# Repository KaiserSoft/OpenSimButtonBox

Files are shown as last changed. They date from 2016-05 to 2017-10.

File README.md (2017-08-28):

Modular Open Sim Racing Button Box
==================================

The Modular Open Button Box (MOBB) project is a complete open source solution to build your own button box. It provides complete plans on how to build your own 
Teensy 3.2 shield, button box ideas, box designs for 3D printers, drill tempaltes for your face plates or just ideas for your own design.    
The design is modular so you may pick and choose from various parts to design YOUR button box the way YOU imagine it.    

example image of the Open Button Box (MOBB) PCB rev5    

Design idea with UV-LEDs to provide illumunation when it is dark
design idea with UV-LEDs

Side by side box design    
side by side sim button box

Two of the boxes used for current development    
two development button boxes

Example of pit limiter switch on older development board   
pit limiter switch example

The PCB
===========
The PCB is a shield for the Teensy 3.2 micro controller board. You may use the provided schematic to build your own on a perfboard, use the provided gerber files to have one manfucatured or contact me to send you one.    
Assembly requires minor soldering skills but assembly is quite easy if you follow the instruction videos.       

The current version supports
* through hole component design for easy soldering
* 32 buttons
* 1 latching toggle switch with LED inside - used to enable/disable the pit limiter
* 3 rotary encoders
* 3 Auxillary ports providing 0-5Volt @ 100mA each
* one handed operation to adjust AUX ports (always have one hand on the steering wheel)
* fully open source in design and code
* code written using the Arduino IDE for easy customizations
* (Optional) 12Volt Fan Board with optical isolation between 12Volt supply and host PC. Connects to one AUX port and controls up to two fans.
image of fan controller board

INSTRUCTIONS & Sources List
===========================
Any documentation in the "Documentation" directory is not up to date anymore!    
I will produce a series of videos explaining how to build the PCB and how to configure the software.     
The build video is available here https://www.youtube.com/watch?v=iexbjr4jJTc      

This is an open source project - contributions are welcome!

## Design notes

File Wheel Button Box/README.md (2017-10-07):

OSW Button Box - DIY Direct Drive Wheel Button Box
===

Image of fully assembled wheel button box

Required Parts
===
* Arduino Pro Micro 16MHz - Will not work with most other Arduinos since they can not act as a HID. Teensy should work as well but it is more expensive.
* 10x push buttons with a thread diameter of around 12mm. The kind with a metal body works as well but they are heavier.    
  Supported Push Buttons
* 1x Arduino Joystick Module - pay close attention to the circuit board since there are different types and the button box only works when the dimensions are correct.  
  Supported Joystick Module
* Coiled Micro USB Cable - this connects the button box to your PC. It needs to be coiled so it can flex all the way to the end stops.

Build Instructions
===
* Print the button box and do basic cleanup. Rough up the sides where the box is split and use glue to join the two halves back together. You don't need much glue since this only makes it easier to install the buttons and cables. The button box will be held in place by the screws connecting the wheel to the mounting hub on the OSW motor.
* Install the buttons and solder the wires in place. Cut the wires long enough so that they can exit the arduino box at the bottom.
* Desolder the connection pin header on your joystick module.
* Solder wires to the joystick module and run them to the arduino box as well
* Ensure that every button is working by using the continuity test setting on your multi meter
* Ensure the joystick is working by testing the resistance
* Add wires for the magnetic paddle shifters as well. I recommend that you don't connect the sifters yet. Simply run wires and solder them to the paddle shifter wires once you are ready to assemble it all.
* Connect all wires as described in "CONFIG.h". Buttons use the "Button_X_Pin" and the joystick the "Joystick_X_Pin" setting.
* Remove some of the plastic on the outside of the micro USB connector. This makes the connector shorter and makes in easier to push it through the hole inside the button box.
* Connect the coiled USB cable to the arduino and upload the scetch to the board
* Test every button and joystick
* Test the buttons again
* Push the arduino into the arduino box at the bottom. Pull extra wires into the button box body and hide them in the wire channel.
* Test the buttons again
* Fill the arduino box with hot glue or silicone sealant. This ensures that the micro USB connector will not disconnect and that the arduino will not move
* Run the rest of the USB cable through wire channel at the bottom of the unit
* Assemble everything and connect the padde shifters
* Mount everything to the OSW and attach the wheel
* All done. You can use the arduino software to change which button sends which command (CONFIG.h file)
* Have fun!
image showing sections described above

Recommended Print / Slicer Settings
===
* Material: PLA
* Layer height: 0.25mm
* Infill: 25% to 30%
* Top/Bottom: 3 solid layers

File and Directory List
===
* **arduino_pro-micro_button_box**    
  This directory contains the Arduino Pro Micro Source Code

* **Face Plate for 320mm Steering Wheel**   
  Contains the STL and 3D source models for the button face plate
  
* **Wheel Box Face Plate for Arduino ProMicro - ONE PIECE**    
  This STL file contains the face plate in one piece. You need about a 200mmx150mm build surface.
  
*  **Wheel Box Face Plate for Arduino ProMicro - TWO PIECES - ONE / TWO**    
  This STL file as the face plate split into two pieces. This will work with a standard 150mmx150mm build surface
  
* **Sparko - Momo - Spacer and Backplate - ProMicro**    
  This is the back plate required to keep the center joystick in place
  
* **Shifter Mount with Joystick Slot**    
  This file contains the paddle shifter mount plate

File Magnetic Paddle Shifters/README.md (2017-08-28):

3D Printed Magnetic Paddle Shifter
---

These 3D printed magnetic paddle shifters are designed to be compatible with most button boxes used in the sim racing community.
The shifter is designed to be compatible with the Omron D2F-01 micro switch. You may use the original Omron part or get cheap knock offs from ebay. 
   
The shifters only require a few parts and are easy to print. Please have a look at the build instruction video for more detail on how to assemble one.

https://www.youtube.com/watch?v=kEENwVqYf5s   

File Overview
---
* The folder "Box Style" contains the current design. It is simpler to build and uses stronger parts when compared to the "Open Design".
* The folder "Paddles" contains different paddle designs. You only need one per shifter.
* The folder "Open Design" contains the older "open style" design. It is more complicated to build and requires exact distance between the lever and the switch. You probably don't want to use this.

Recommended printer/slicer settings
---
* The shifter body should be printed with at least 20% honeycomb infill
* The lever should be printed solid
* The paddles work great with 30% honeycomb infill
* The part is build with a 0.25mm layer height in mind
* Material used for my prints is PLA

Bill of Materials
---
The following parts are required to assemble one shifter unit. Each shifter requires on micro switch. The type 
depends on which Body you are printing.

* 2x 623ZZ ball bearing
* 1x M3x45mm flat head machine screw
* 1x M3 nut / locking nut for machine screw
* 2x 12x3mm neodymium magnet (round disk shape). 
You may order additional magnets to adjust the force required. I recommend at least one more 12x2mm
* 2x M3x12mm counter sunk screw for mounting the paddles to the shift lever
* 2x M3 nut for the M3x12mm counter sunk screw
* 2x M3 countersunk screw for mounting the unit to your button box or wheel
* 1x Omron D2F-01 or D2F-01-D3 micro switch or cheap clones D2FC-F-7N on ebay

Media
---
List of videos related to these magnetic paddle shifters
* Assembly video - https://www.youtube.com/watch?v=kEENwVqYf5s
* Magnetic Paddle Shifter durability testing (open design) - https://www.youtube.com/watch?v=JnYoWvMd-ec
* Testing in game, mounted to G27 wheel base (open design)  - https://www.youtube.com/watch?v=P4YznCb-aOs
* Testing with OSW direct drive wheel (open design)  - https://www.youtube.com/watch?v=NF07MALhuUw

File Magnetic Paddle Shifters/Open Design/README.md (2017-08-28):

3D Printed Magnetic Paddle Shifter - Open Design
---
Please note, this design has been replaced by the "Box Style" since the box style is easier to build and used stronger components. This design still works fine but I don't recommend you use it if you are building a new set of paddle shifters.
   
These 3D printed magnetic paddle shifters are designed to be compatible with most button boxes used in the sim racing community.
There are two versions of the shifter. One is for a micro switch with "pin plunger", like the Omron D2F-01. The other version is for a micro switch with "hinge lever", like the Omron D2F-01L.   
The "pin plunger" version requires a more accurate printer since it is using tighter tolerances. The "hinge lever" part is more flexible with dimensional accuracy but the "hinge lever" switch may not be as reliable.
   
The shifters only require a few parts and are easy to print. Please have a look at the build instruction video for more detail on how to assemble one.

https://www.youtube.com/watch?v=EhsOMB1wswM 

Recommended printer/slicer settings
---
* The shifter body should be printed with at least 15% infill
* The lever should be printed solid
* The paddles work great with 30% honeycomb infill
* The part is build with a 0.25mm layer height in mind
* Material used for my prints is PLA

File Overview
---
* The folder "Body for Pin Plunger Switch" contains the body part designed for the "pin plunger" type of button
* The folder "Body for Hinge Lever Switch" contains the body part designed for the "hinge lever" type of button
* The folder "Lever" contains the Lever used by both body styles

Bill of Materials
---
The following parts are required to assemble one shifter unit. Each shifter requires on micro switch. The type 
depends on which Body you are printing.

* 2x MR52ZZ ball bearing
* 1x M2x40mm flat head machine screw
* 1x M2 nut for machine screw
* 2x 12x3mm neodymium magnet (round disk shape)
* 2x M3x10mm counter sunk screw for mounting the paddles to the shift lever
* 2x M3 nut for the M3x10mm counter sunk screw
* 2x M3 countersunk screw for mounting the unit to your button box or wheel
* 1x Omron D2F-01 or D2F-01-D3 micro switch or cheap clones D2FC-F-7N on ebay (Body for Pin Plunger Switch)
* 1x Omron D2F-01L or D2F-01L-D3 micro switch (Body for Hinge Lever Switch)

Media
---
List of videos related to these magnetic paddle shifters
* Magnetic Paddle Shifter durability testing - https://www.youtube.com/watch?v=JnYoWvMd-ec
* First assembly video - https://www.youtube.com/watch?v=EhsOMB1wswM
* Second assembly video - https://www.youtube.com/watch?v=DKPDk3TvZT4
* Testing with OSW direct drive wheel - https://www.youtube.com/watch?v=NF07MALhuUw

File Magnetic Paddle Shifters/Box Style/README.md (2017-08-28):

Overview Box Style
---

Please see README.md in the "Magnetic Paddle Shifters" directory. This file only explains the different file types.

* SLDPRT - these are the main 3D model files. CAD software is Solidworks 2014
* STEP - these are exports of the SLDPRT file. You should be able to use these to import the 3D model into the CAD software of your choice.
* STL - these are the files you may use to print the object. These are oriented correctly so just add them to your slicer to create the gcode file for your printer.

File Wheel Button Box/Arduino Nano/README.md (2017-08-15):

Arduino Nano Button Box
---

Update 2017-08-15
WARNING: The code in this directory is not finished. The serial communication from the Arduino Nano to the VB.NET program is working but 
I ran into an issue when I tried to send the key presses to iRacing. It works in Windows Editor, other programs and even the iRacing chat box but 
it stops working once I enter the car. This may be an issue with which window has focus so the solution may be to detect the iracing window and 
explicitly send the output to it. I may investigate in the future or if someone else feels like testing it .... feel free.
I have decided to switch to an Arduino Pro Micro since that unit is about the same price as the Nano but offers USB HID support out of the box.
This will eliminate the requirement for the VB.NET program to send the keypresses since the Pro Micro will act as a true HID.
I was not aware of the Pro Micro before, that would have been the better solution to begin with.... I am also investigating using an STM32 since they are also very cheap and very capable. This will be a great replacement for the rather expensive Teensy 3.2

ANYWAY - DO NOT USE THE CODE IN THIS DIRECTORY AND EXPECT IT TO WORK IN GAME! - You have been warned!
/End of Update 2017-08-15

DO NOT USE THIS YET! This is mostly just code to test the concept!

This directory will contain the code for the arduino nano  to work as a simple stand alone button box
and a very simple Windows VB.NET programm to receive the button presses via the serial interface.
Since the Nano can not run as a HID the Windows programm will send the keystrokes to the computer.

Arduino Nano Pinout
---
This button box will support up to 13 push buttons with one analog joystick
The pinout is defined like this:

* D2-D8,D11,D12 are used for push buttons - 9 Buttons
* D13 feedback LED
* A0,A1,A2,A3 are used for push buttons - 4 Buttons
* A6 used for Joystick 1 x/y-axis
* A7 used for Joystick 1 x/y-axis
* D9-D10 reserved for other functions (PWM pins)
* A4,A5 reserved for possible i2c OLED display or LED RPM bar using i2C port extenders

Windows Receiver
---
Windows Receiver is a very simple VB.NET program which listens to specific commands.
It will work with any other micro controller as long as it follows the following rules.
Supported Commands:
	* 'wr' - Windows Receiver will send this on the serial port after the "Connect" button is pressed.
	* 'nr' - Windows Receiver expects to receive this after sending 'wr'. It will not accept button commands without receiving this string
	* 'ws' - Windows Receiver sends it before closing the serial port. The Arduino Nano must stop sending button commands once this has been received
	* 'ns' - Windows Receiver expects to receive this after 'ws' has been sent.
	* 'B[1-13]' - The Arduino Nano may send button presses by indicating which button was pressed. Example: 'B1', 'B2', 'B6' .....     
		The button number must match the setting in the Windows Receiver GUI
	* 'J[1-2]' - Just like button but for analog "jostick". Send 'J1' or 'J2' for one direcion where the number must match the GUI
	* 'K[1-2]' - Sends 'K' instead of 'J' when the same axis is moved in the opposite direction

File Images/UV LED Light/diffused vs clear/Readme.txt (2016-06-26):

LEDs have been diffused with fine sandpaper. 
Diffused LED focus the light much closer which should be much better to illuminate the button box labels.

The LEDs in the image where bought on Amazon.de
"10 Stück 10mm Ultra hell UV-LED " or "10 piece 10mm ulta bright UV-LED"

Specs:
Color: Ultraviolet
Size: 10mm
Lens type: clear
Wave length: 400-405nm
light intensity: 80-120mcd
DC current: 20mA
DC forward voltage: 3,2-3.4V

https://www.amazon.de/St%C3%BCck-10mm-Ultra-hell-UV-LED/dp/B008U1OEIK

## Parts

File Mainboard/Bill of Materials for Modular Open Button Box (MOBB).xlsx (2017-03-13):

Modular Open Button Box (MOBB) PCB rev 1.0 - Bill of Materials for non-SMD design
QTY | Name | PCB Reference | Comment / Values / Package
4 | 74HC4051 | U1, U2, U3, U4 | DIP-16
4 | NPN (CBE) Transistor | Q1, Q2, Q3, Q4 | 5V/100mA (CBE) TO-92
2 | PTC fuse | PTC1, PTC2 | Ihold:0.30/Itrip0.60A
1 | IC Socket for Teensy | U5 | DIP-28 with:15.24mm
3 | 10K (9+1 pin) resistor network | RR1, RR2, RR3 | star configuration, 2.54mm pitch
1 | 10K (5+1 pin) resistor network | RR4 | star configuration, 2.54mm pitch
1 | 100K 1/4Watt resistor | R10
1 | 10K 1/4Watt resistor | R1
1 | 10K (10pin) resistor network | RR5 | parallel configuration, 2.54mm pitch NOTE: may use 5x 10K 1/4Watt resistors instead
1 | 1K (10pin) resistor network | RR6 | parallel configuration, 2.54mm pitch NOTE: may use 5x 1K 1/4Watt resistors instead
1 | 1x2 pin header straight | P7 | 2.54mm pitch
1 | 1x2 pin header angled | P4 | 2.54mm pitch
1 | 1x6 pin header angled | P5 | 2.54mm pitch
2 | 2x3 pin header angled | P1, P3 | 2.54mm pitch
1 | 1x32 pin header angled | P6 | 2.54mm pitch
1 | 1x5 pin header angled | P14 | OPTIONAL: for "Extra Pins" - not used
1 | 5cm hookup wire | P2 | for +12V source
1 | 1x1 pin header connector |  | for hookup wire on P2, connector for Teensy side
1 | 10V 100uF electrolytic capacitor | C7 | radial, 2mm pitch

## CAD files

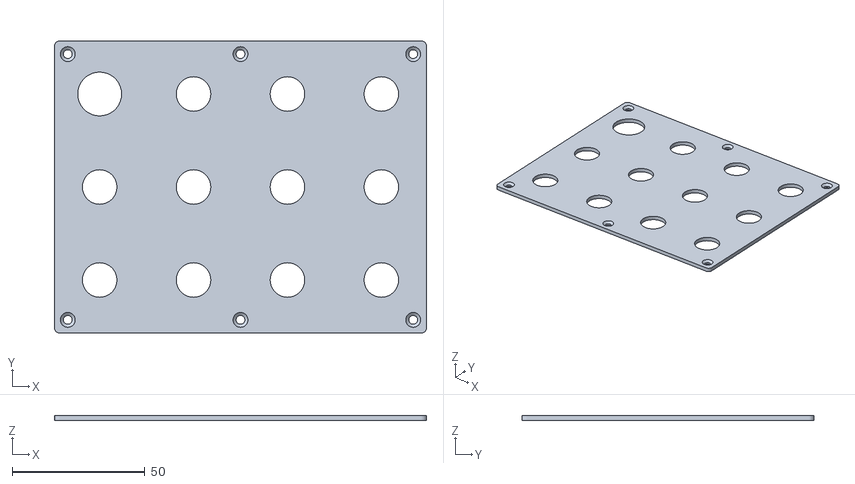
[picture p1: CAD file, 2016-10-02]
Cases and Enclosures/140mm wide/STL/Main Module - Face Plate - v5 - TOP ROW 1x16mm + 3x13mm - NO ENCODERS.STL
140.0 x 110.0 x 2.00

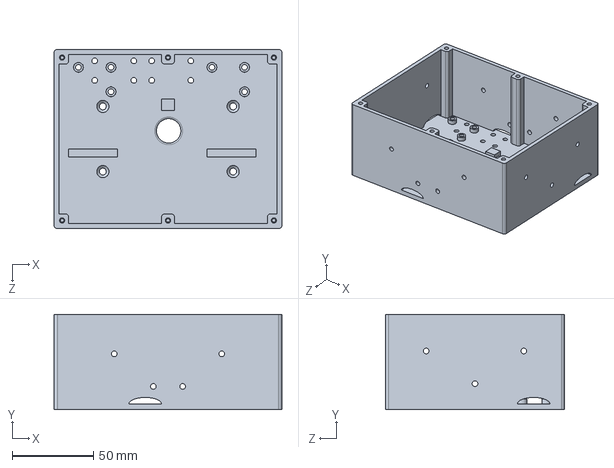
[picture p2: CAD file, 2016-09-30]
Main Module/Case/140mm wide/Main Module - Body - v5.SLDPRT
140.0 x 58.5 x 110.0 mm

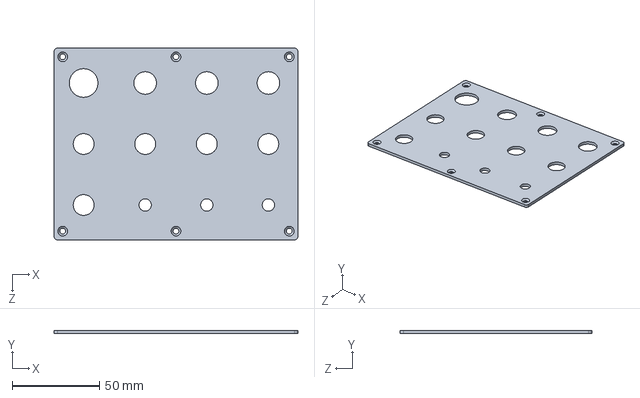
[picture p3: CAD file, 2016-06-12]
Main Module/Case/140mm wide/Main Module - Face Plate - v4.SLDPRT
140.0 x 2.00 x 110.0 mm

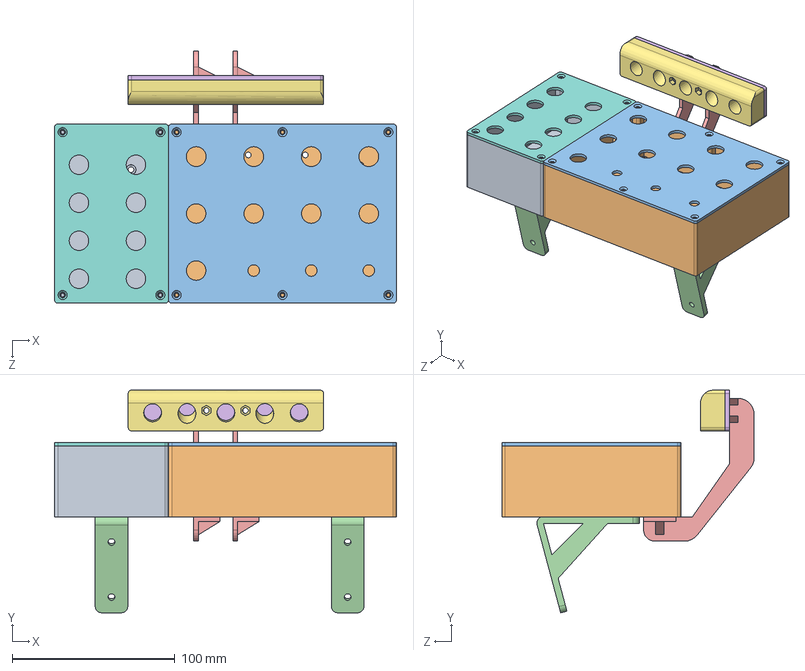
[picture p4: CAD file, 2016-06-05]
Cases and Enclosures/Side Box Left/Side Box Left assembled with Main Body - v2 Face Plate.SLDASM
210.0 x 136.8 x 154.9 mm
Side Box Left - Body - v2
Main Module - Body - v4
Main Module - Face Plate - v4
Mount Bracket 75 x 2
UV Lamp Mount - 10mm LED - MOUNT x 2
UV Lamp Mount - 10mm LED - COVER
UV Lamp Mount - 10mm LED - BASE
Side Box Left - Face Plate v2

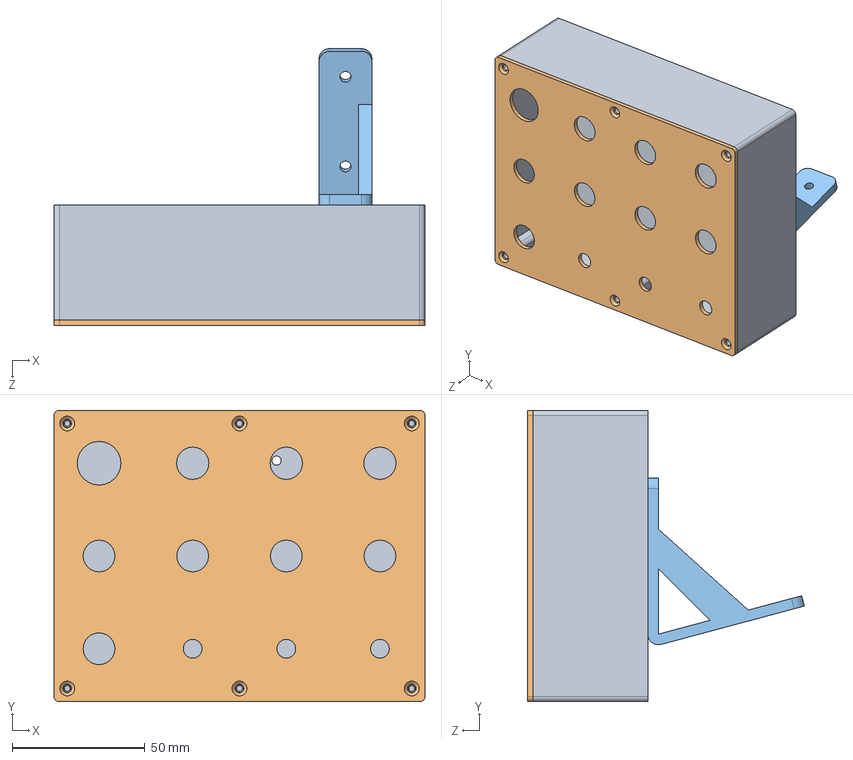
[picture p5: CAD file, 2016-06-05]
Main Module/Case/140mm wide/Main Module - Fully Assembled - v4.SLDASM
140.0 x 110.0 x 104.5 mm
Main Module - Body - v4
Main Module - Face Plate - v4
Mount Bracket 75

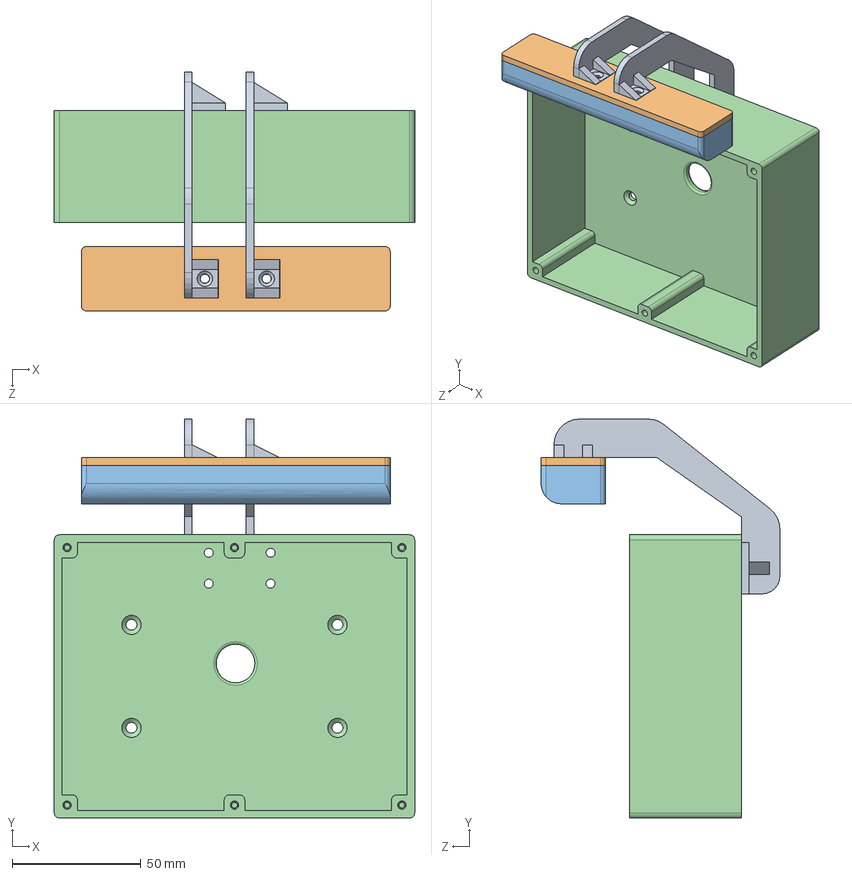
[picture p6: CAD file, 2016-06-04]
UV Lamp Holder/UV Lamp Mount - 10mm LED.SLDASM
140.0 x 154.9 x 92.8 mm
UV Lamp Mount - 10mm LED - MOUNT x 2
UV Lamp Mount - 10mm LED - COVER
UV Lamp Mount - 10mm LED - BASE
Main Module - Body - v4

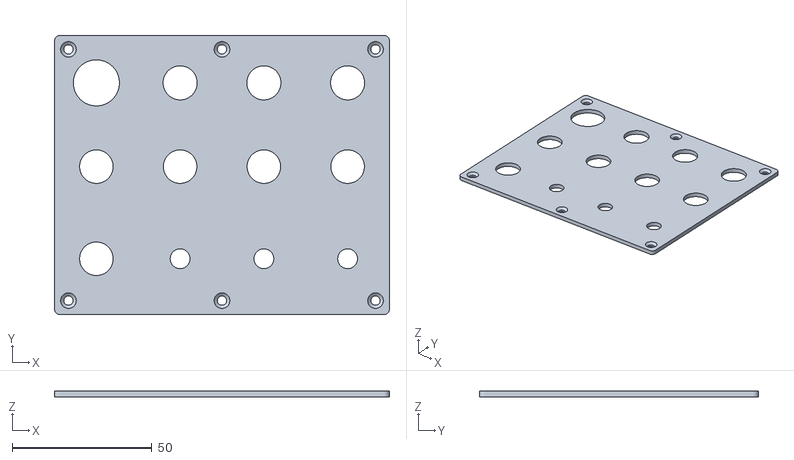
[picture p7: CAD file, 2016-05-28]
Cases and Enclosures/120mm wide/Main Module - Face Plate - v3 - Top Row Ignition + 3 buttons.STL
120.0 x 100.0 x 2.00

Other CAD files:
Cases and Enclosures/140mm wide/Main Module - Body - v6-RC6_PCB.SLDPRT
Cases and Enclosures/140mm wide/Main Module - Face Plate - v5.SLDPRT
Cases and Enclosures/140mm wide/STL/Main Module - Face Plate - v5 - TOP ROW 1x pit limiter + 1x16mm + 2x13mm - NO ENCODERS.STL
Cases and Enclosures/120mm wide/Main Module - Face Plate - v3.SLDPRT
Cases and Enclosures/140mm wide/STL/Main Module - Face Plate - v5 - TOP ROW 4x13mm.STL
Cases and Enclosures/120mm wide/Main Module - Body - v3.SLDPRT
Cases and Enclosures/140mm wide/STL/Main Module - Face Plate - v5 - TOP ROW 1x16mm + 3x13mm.STL
Cases and Enclosures/140mm wide/STL/Main Module - Face Plate - v5 - TOP ROW 4x13mm - BOTTOM encoders left.STL
Cases and Enclosures/120mm wide/Main Module - Face Plate - v3 - Top Row 4 Buttons.STL
Cases and Enclosures/140mm wide/STL/Main Module - Body - v5 - WITH BOX MOUNT ALL SIDES.STL
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

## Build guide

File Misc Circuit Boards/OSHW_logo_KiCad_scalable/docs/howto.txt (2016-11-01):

How to make your own:
---------------------

Watch / read this first:

* http://www.kicad-pcb.org/display/KICAD/Videos+by+zupnikal

The last two videos should be helpful for how to create a custom .emp file from images.

* http://www.re-innovation.co.uk/web12/index.php/en/blog-75/230-adding-logo-to-kicad

If you use linux (which you should), you don't have to use the online-scaler. Just use the scripts!

---

* Create a folder to hold your new footprint library.
* Copy the scripts 'make_lib.sh' and 'scale.pl' into that folder.
* Make sure these files are executable (chmod u+x ...).
* Copy your custom .emp file into that foler.

* Run the 'make_lib.sh' script as follows:

./make_lib.sh input-file.emp lib-name.mod START END

START and END are placeholders for positive integer numbers (1,2,3...) that determine
the range of created footprint sizes. The units are metric (mm).

The 'lib-name.mod' file will show up in the 'lib' sub-folder. Add it to your pcbnew
library settings as usual.

Footprints that are created for back-layers are automagically mirrored horizontally.
To place them onto a back-layer, hover the mouse-pointer over them and press 'f' for 'flip'.

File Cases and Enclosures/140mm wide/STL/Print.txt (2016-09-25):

Software used: Slicer 1.2.9

* Face Plate
	- 25% infill, combine every 2 layers
	- 3 top shells, 2 bottom shells

* Body
	- 20% infill, combine every 2 layers
	- 2 top, 2 bottom shells

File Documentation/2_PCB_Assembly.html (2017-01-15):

## PCB Assembly Instructions

Add Image of PCB 1.0 here

1. Soldering the PCB is shown in the following YouTube videos. Below is a list of the required parts
  - 4x 74HC4051 multiplexer DIP-16 (NOT 74HCT4051)
  - 4x 5V/100mA NPN (CBE) transistors TO-92
  - 2x PTC fuse 5mm leads Ihold:0.30/Itrip0.60A
  - 1x IC socket 28pins 15.24 mm (for Teensy)
  - 3x 10K resistor network 10pin(9+1) (2.54mm star configuration)
  - 1x 10K resistor network 6pin(5+1) (2.54mm star configuration)
  - 1x 100K 1/4 watt resistor
  - 1x 10K 1/4 watt resistor
  - 5x 10K 1/4 watt resistors OR 1x 10K resistor network 10pin 2.54mm parallel configuration)
  - 5x 1K 1/4 watt resistors OR 1x 1K resistor network 10pin 2.54mm parallel configuration)
  - 1x pin header straight 1x2 2.54mm
  - 1x pin header angled 1x2 2.54mm
  - 1x pin header angled 1x6 2.54mm
  - 2x pin header angled 2x3 2.54mm
  - 1x pin header angled 2x32 2.54mm
  - OPTIONAL: 1x pin header angled 1x5 2.54mm (for "Extra Pins")
  - 1x 5cm hookup wire
  - 1x pin header straight 1x1 female connector (to 5V on Teensy)
  - 1x LED with wire (user feedback LED)
  - 1x 10V 100uF radial capacitor
2. dsfsf

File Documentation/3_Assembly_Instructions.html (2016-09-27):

## Assembly instructions

Add Image of Proto 2 here

1. Begin by printing the main case and a face plate found in "Main Module\Case\140mm wide\STL\". Never mix two different versions of body and face plate. A version 3 body will most likely not work with a version 4 face plate!
  - Main Module - Body - v4 This is the main body of the button box. The "STAND ALONE" version does not come with additional mounting holes for the side box.
  - Main Module - Face Plate - v4
    - TOP ROW 1x16mm + 3x13mm This face plate has a hole for a 16mm switch in the top left corner. 
    - TOP ROW 4x13mm This face plate uses the same buttons on the top row. 
    - NO HOLES WARNING You need to add holes to this face plate. Only use this if you don't have access to SolidWorks.
2. The box can be mounted so the bottom sits flush on the table ("Flush Brackets") or the bottom of the box will sit below whatever it is mounted to ("Lowered Brackets"). The filename also indicates the type of bracket. A "90 degree" bracket will make the box sit perpendicular to your desk while a "75 degree" bracket is tilted back by 25 degrees. Add Image of Proto 2 Mount here
  - Mount Bracket 90 degrees The box stand vertical with this bracket.
  - Mount Bracket 75 degrees The box will be tilted back by 25 degrees with this bracket.
3. Next, screw the switches onto the face plate and heat up your soldering iron. Make soldering easy by orienting all switches the same way. 
4. Start with soldering all ground terminals together as seen in the image below. Be careful with the small plastic switches from China. I solder these at 300C for 2 seconds. Let the part cool down before you try again if you don't get the joint done quickly. My FFB wheel generates a lot of vibration which will be transfered into the button box as well. So I stick the wire through the eye on every contact to make the joint stronger.  
5. Next solder wires to the remaining terminals. These need one wire per terminal and should be long enough to reach the main board once it is mounted in the case. Notice how the wires are not the same length once they are bundeled up. Yes, I had to solder small extensions to all the short wires you see in the image - so much fun. 
6. At this point you need to decide if you want to build only the main box or if you want to connect the side box as well. This can be changed later but you have to desolder a bunch of wires.
  - Stand alone Connect one wire to GND (ground) on the teensy
  - Multi Plexed for upto 32 buttons and 3 rotary encoders Connect one wire to GND (ground) on the teensy
7. Now connect the other button terminals to the Teensy 3.2 board. Start with GND (Ground), then pins 1 to 12 and finally pins 14-23. DO NOT USE Pin 13, it is for the LED so connecting a switch may not work without removing the LED first. It should look similar to this when you are done. Make sure you place the Teensy behind the top row since those switches are the shortest and give the Teensy more room in the case. Make sure you write down the pin number for every buttong! 
8. (Optional but highly recommended) Verify the operation of every switch with a multimeter. Set it to test continuity (beeps when you short the leads), connect one lead to ground and the other to the switch terminal connected to the Teensy. The multimeter should only beep when you press the button. Also test that you don't have a short to the button next to it since a short may happen when you solder the wires to the Teensy board.
9. TO DO - Add Info on how to instal Arduino IDE with Teensy extension!!!!!!!!!!!!!!!!!!!!!!!!!!!!!
10. Open the Sketch and click on the "CONFIG" tab within the sketch. Here you will see a list of every button with the pin and function assigned to each one. Take a look at the following tables. These are the keys you can tell then Teensy to send to your computer.

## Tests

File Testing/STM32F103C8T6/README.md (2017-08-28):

Wheel Button Bux based on STM32F103C8T6
============

This directory contains the code for a sim racing button box using the STM32F103C8T6 development boards.
* Tested on STM32F103C8T6

*WARNING* The USB connector on my board was not soldered around the clamps. You should apply solder if you want to ensure long life in an environment with a lot of vibration.

Arduino Requirements
====================
You will need the following equipment to install the Arduino Bootloader onto the board.
* An STM32F103C8T6 development board
* A ST-Link v2 programmer for STM8 and STM32. I am using a 3€ clone from ebay. Search for "ST-Link v2 programmer" and you will find a lot to chose from. They should be all the same and only differ in color.

Arduino IDE Setup
=======
Since the STM32F103C8T6 is not supported out of the box you will need to install the Arduino Bootloader and add support for the STM32F103C8T6 
to the IDE. The following steps should get your up and running. Make sure you follow each step or it may not work!
* Download and install the Arduino IDE 1.8.x from https://www.arduino.cc/en/Main/Software
  * Start the Arduino IDE and open the "Boards Manager" under "Tools" => "Board"
  * Enter "arduino zero" into the search box, click on the "Arduino SAMD Boards" result and then on "Install"
  * Close the IDE now
* Clone https://github.com/KaiserSoft/Arduino_STM32 or download https://github.com/KaiserSoft/Arduino_STM32/archive/master.zip    
  * Extract the archive and copy the "Arduino_STM32-master" folder into "My Documents\Arduino\hardware". Create the "hardware" directory if it does not exist yet
  * Goto "My Documents\Arduino\hardware\Arduino_STM32-master\drivers\win" and run "install_drivers.bat"
* Download and install "STM32 ST-LINK Utility" (Part number STSW-LINK004  from http://www.st.com/en/embedded-software/stsw-link004.html
  This is free software but requires registration.
* Connect the ST-Link v2 programmer to your computer and ensure that you see a "STM32 STLink" in the Device Manager. This should be listed unter "Universal Serial Bus devices" in Windows 10. Disconnect the programmer for now.
* Download the "STM32duino-bootloader" from here https://github.com/rogerclarkmelbourne/STM32duino-bootloader/tree/master/binaries
  Look for the file "generic_bootXX_pc13.bin" where PC13 is the pin where the LED is connected on the board. This is not the same on all boards but it is marked on my board as PC13.    
  Check the following ReadMe for details https://github.com/rogerclarkmelbourne/STM32duino-bootloader/blob/master/README.md
* Connect the ST-Linkv2 programmer to the four pins towards the back of the STM32F103C8T6 board.    
  Pay VERY close attention to the voltage line! ONLY CONNECT 3VOLTS to the board since you will destroy the board if you accidentially connect 5Volts!
  * Connect the ST-Link 3V line to the pin marked 3.3, SWDIO to DIO, SWCLK to DCLK and GND to GND. Double check that you connected it correctly!
  * Move the jump that is next to the row of pins (Boot1) to pin 1. If you hold the board with the USB connector to the right, then it is the jumper towards the bottom.
  * Connect the SW-Link v2 programmer directly to your computer. Do not use a USB extension cable for this.
* Start "ST32 ST-Link Utility" and click on "Target => "Connect"
  * Click on "Target" => "Program & Verify", a file selection windows will open. Select the "generic_bootXX_pc13.bin" file you downloaded earlier.
  * Ensure that "Skip Flash Erase" and "Skip Flash Protection verification" are NOT checked and that "Verify while prgramming" is selected.
  * "Reset after programming" should be checked but "Full Flash memory Checksum" should NOT be checked.
  * Click "Start" to write the image to the device.
  * You should see "Memory programmed in xxs and yyms" followed by "Verification...OK"
  * Disconnected the STM32F103C8T6 and set the Boot1 jumper back to pin 0
* At this point the Arduino Bootloader is installed and you should be able to upload programs using the Arduino IDE. You may double check this by opening the Device Manager. Under "Ports (COM & LPT)" you should see a "Maple Serial (COM)" device.
* Test the functionality by opening the Arduino IDE and upload the "Blink" Example
  * Click "File" => "Examples" => "01.Basics" => "Blink"
  * Click "Tools" => "Board:" and select the "Generic STM32F103C series" from the menu
  * Make sure that the following is selected
    * Variant: STM32F103C8 (w0k RAM, 64k Flash)
    * USB Type: Keyboard + Mouse
	* CPU Speed(MHz): 48Mhz (Slow - with USB)
	* Upload method: STM32duino bootloader
	* Port: The COM port used by your device
  * Click "Upload" and check that your STM32F103C8T6 starts blinking

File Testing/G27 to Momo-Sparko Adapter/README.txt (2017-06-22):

This adapter is for testing only! The G27 is not strong enough to handle 
a heavier wheel while still delivering proper force feed back.

I am using this adapter to temporarily mount my Beltenick steering wheel so I can develop my 
3D printed magnetic paddle shifters.

Dimensions are based on the following template
https://www.dropbox.com/s/hmzmvewwpmdi0c5/Logitech%20G25_G27%20Steering%20Wheel%20Hub%20Template.pdf#

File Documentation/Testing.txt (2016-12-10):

File to collect information. To be turned into an HTML file later

Steps to verify the assembled PCB.

Please note, button detection is slower when "OutputSerial" is enabled. You need to hold the button for a 
bit longer to get detected. Disable the option once you are done setting everything up.

* Open latest firmware with Arduino IDE
* Set to Teensy 3.2 with "Serial + Keyboard + Mouse + Joystick"
* In Config.h, set OutputSerial to 1
* In AUXPins.h, set EnableAux1, EnableAux2, EnableAux3 to 0
* Upload Sketch to Teensy
* Open Serial Console from Arduino IDE

* Start with header pins 1-32, use the same button to test every pin. 
  You should see feedback in the Serial Monitor. The sequence is (US-layout) "abcdefghijklmnopqrstuvwxABCDEFGH"
  NOTE: There is no "y" or "z" in the output

* Use one encoder to test pins 1A through 3B. 1 = left, 2 = center, 3 = right
  You should see output like this "EncLeft:right / check_rotary_encoders()"
  Rotate the plug if the "left" / "right" direction is reversed

* In AUXPins.h, set EnableAux1, EnableAux2, EnableAux3 to 1
  also set AUX1_Button_Auto_Hold to 0 for every AUX port
* Upload the new scetch
* Connect an LED or your multimeter to AUX1, AUX2, AUX3
* Connect a switch to pin 1, 2 and 3 on the 1-32 pin header
* connect the 5V connector
* Push and hold the button connected to pin 1 and turn the encoder on the right
* You should see the voltage on the port increase with every turn. The maximum will be around 5V, depends on your USB power source
* Now do the same with the rest and ensure all ports work

* Connect a latching switch to the "Pit" pins
  You should see "Pit limiter ON
" when you activate it and "Pit limiter OFF" when you flip the switch again

* "Extra Pins" are not used at the moment

* The PCB should be functional at this point.
* DON'T FORGET to setOutputSerial to 0 in Config.h
  This will ensure that all of the Teensy CPU power is dedicated to handeling button processes
  and not waste any on sending serial messages.

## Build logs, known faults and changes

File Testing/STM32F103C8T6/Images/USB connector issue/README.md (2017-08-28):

USB Connector issue with STM32F103C8T6
======================================

The following image shows the USB connector issue with the STM32F103C8T6 module.
The pins along the housing are not soldered so the SMD pins and traces have to take all the force.

It is recommended that your solder the connector in place. Depending on your application, you may also consider covering the 
entire connector with epoxy or hot glue to ensure long time reliability.

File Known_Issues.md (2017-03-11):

KNOWN ISSUES
============

fan board RC3
=============
* not manufactured yet / not tested

fan board RC2
=============
* LED can not be turned off by the jumper. it is always on when the load is on     
  Solution: Has been fixed in fan board RC3

fan board RC1
=============
* through holes for fan and power headers are too tight     
  Solution: Has been fixed in fan board RC2

Mainboard - PCB v1.0
========
* no known issues

Mainboard - PCB RC5
=======
* Encoder Push Buttons are not working anymore - discovered 09.12.2016    
  This issue is caused by all multi plexed pins beeing pulled LOW when idle and HIGH when pushed. So far the  encoder buttons where connected the other way around.    
  Solution: All switches connected to multiplexers need to use the 32 pin header. Connect switches to "+" and "S" pin on 1-32 header and the buttons on rotary encoders will work as well.
  Note: Keep two of the three encoder pins connected to "Encoders" on PCB and center pin to ground.

Mainboard - PCB <RC5
========
* multi plexed pins are floating    
  This works with hock up wire but fails with tiny traces using a manufactured PCB.     
  Solution: Has been fixed in PCB RC5

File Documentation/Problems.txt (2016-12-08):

Quick Text file to keep track of some issues and how to fix them.
Use them for a guide or FAQ later

* Button presses are unreliable and/or one button triggers two different key presses. Some pins should not trigger a keypress
  - Check continuity of all 32 pins. Every pin must short circuit to one pin on a multiplexer and 10K to Ground
  - Check continuity of multiplexer pins 11,10,9. 
    Each pin is connected to the same pin on every multiplexer and to pins 0,1,2 on the Teensy. I had a bad solder joint on pin 0

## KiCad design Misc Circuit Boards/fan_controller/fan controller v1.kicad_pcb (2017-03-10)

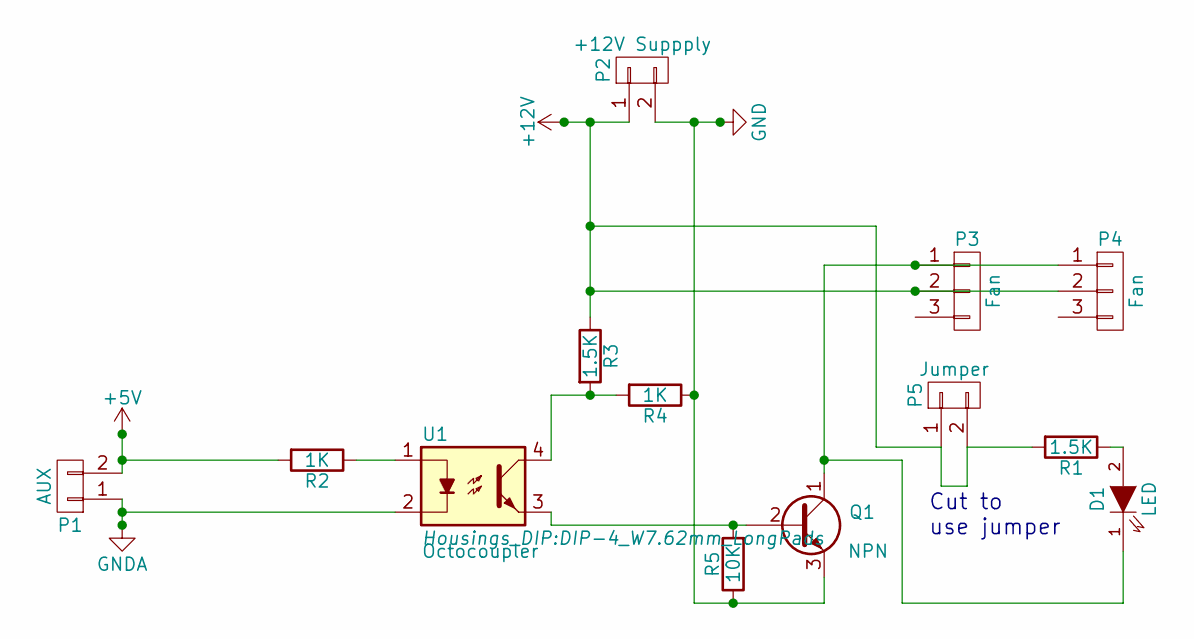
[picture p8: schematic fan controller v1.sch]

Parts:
D1: LED; LED-3MM
P1: AUX; Screw_Terminal_5mm
P2: +12V Suppply; Screw_Terminal_5mm
P3, P4: Fan; Molex-KK-1x3P
P5: Jumper; Pin_Header_Straight_1x02
Q1: NPN; TO-92_Inline_Narrow_Oval
R1, R3: 1.5K; Resistor_Horizontal_RM7mm
R2, R4: 1K; Resistor_Horizontal_RM7mm
R5: 10K; Resistor_Horizontal_RM7mm
U1: Octocoupler; DIP-4_W7.62mm_LongPads

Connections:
+5V: P1.2, R2.2
+12V: P2.1, P3.2, P4.2, P5.1, P5.2, R1.2, R3.1
GND: P2.2, Q1.3 (E), R4.1, R5.1
GNDA: P1.1, U1.2
unnamed: D1.1 (K), P3.1, P4.1, Q1.1 (C)
unnamed: D1.2 (A), R1.1
unnamed: Q1.2 (B), R5.2, U1.3
unnamed: R2.1, U1.1
unnamed: R3.2, R4.2, U1.4

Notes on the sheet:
Cut to use jumper

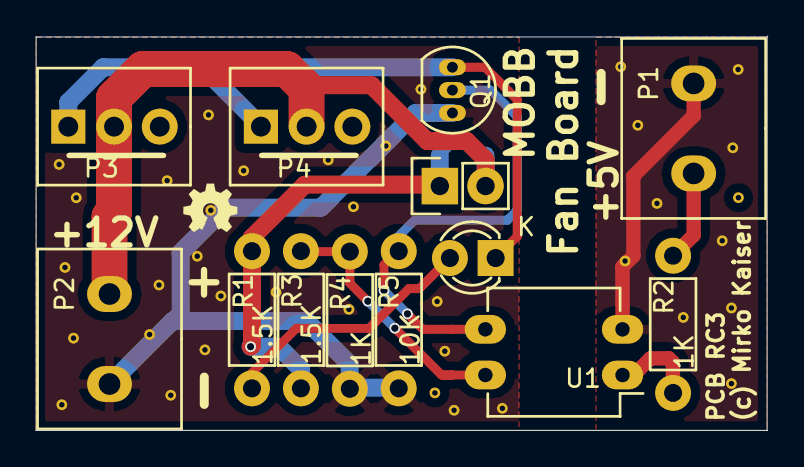
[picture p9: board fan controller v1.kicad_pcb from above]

Board: 2 copper layers, 40.6 x 21.9 mm, 13 parts (0 on the bottom side), 9 nets.

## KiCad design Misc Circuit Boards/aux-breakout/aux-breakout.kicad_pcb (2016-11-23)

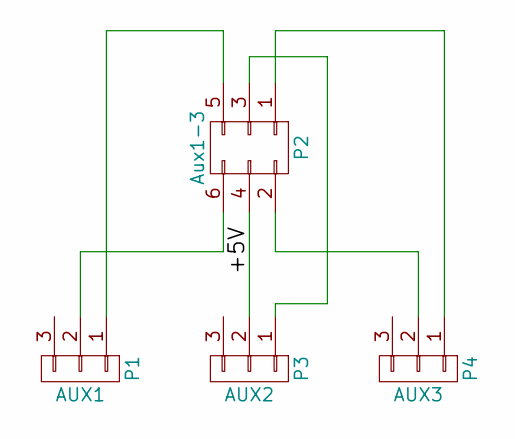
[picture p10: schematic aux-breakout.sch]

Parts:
P1: AUX1; Molex-KK-1x3P
P2: Aux1-3; Pin_Header_Angled_2x03
P3: AUX2; Molex-KK-1x3P
P4: AUX3; Molex-KK-1x3P

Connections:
/+5V: P2.4, P3.2
unnamed: P1.1, P2.5
unnamed: P1.2, P2.6
unnamed: P2.1, P4.1
unnamed: P2.2, P4.2
unnamed: P2.3, P3.1

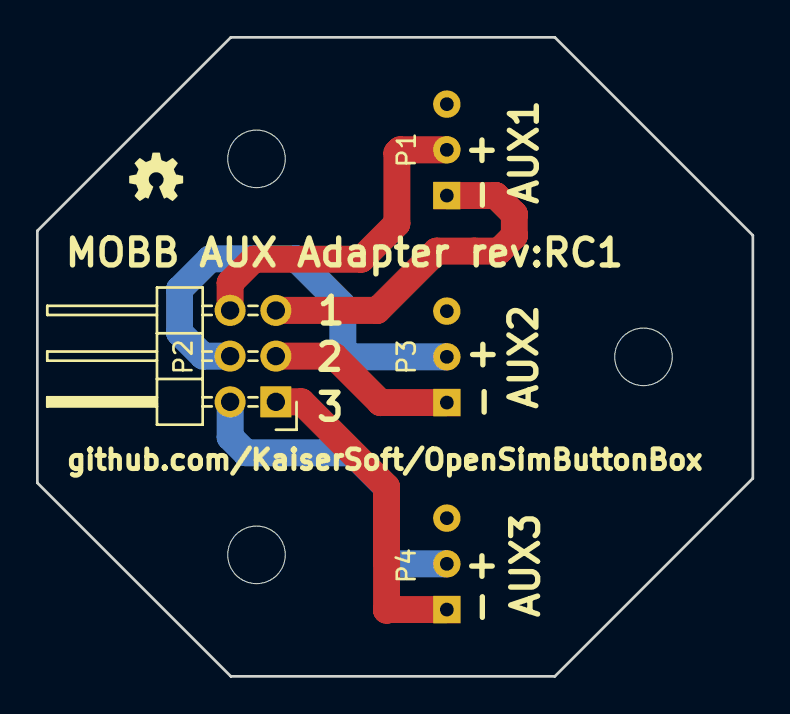
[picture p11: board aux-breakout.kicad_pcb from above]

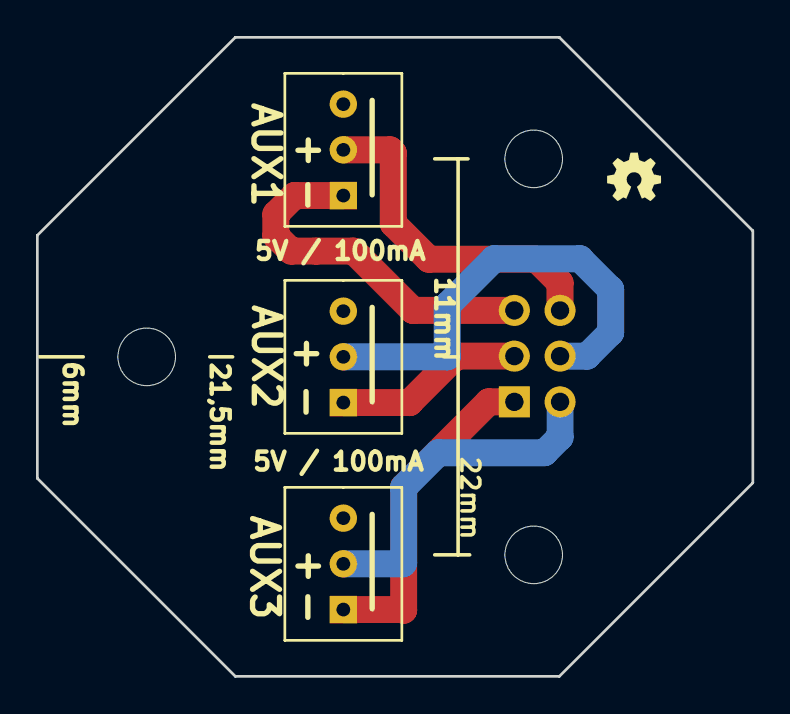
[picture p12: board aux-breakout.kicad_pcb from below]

Board: 2 copper layers, 39.8 x 35.5 mm, 4 parts (3 on the bottom side), 6 nets.

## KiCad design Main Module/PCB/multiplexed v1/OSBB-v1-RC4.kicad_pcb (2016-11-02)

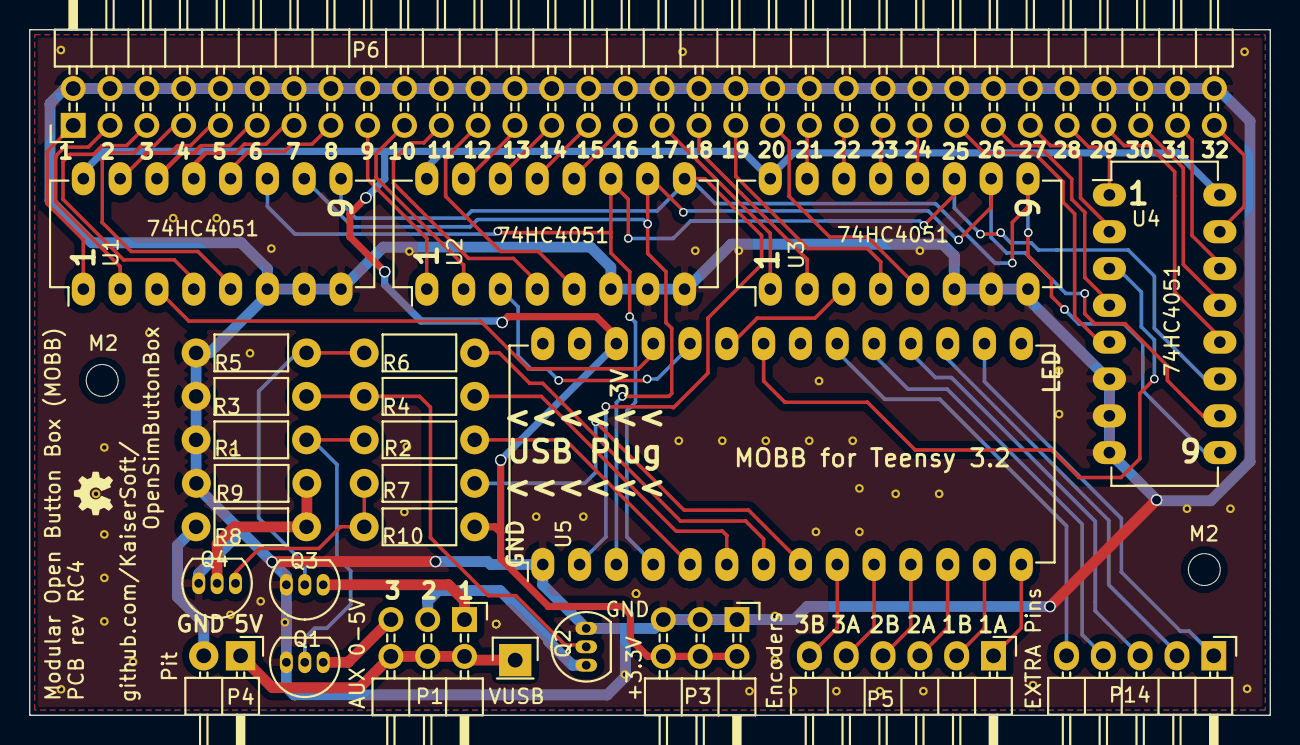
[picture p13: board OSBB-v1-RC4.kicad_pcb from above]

Board: 2 copper layers, 85.6 x 47.3 mm, 26 parts (0 on the bottom side), 66 nets.

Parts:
P1: AUX 0-5V; Pin_Header_Angled_2x03
P2: VUSB; Pin_Header_Straight_1x01
P3: +3.3V; Pin_Header_Angled_2x03
P4: Pit; Pin_Header_Angled_1x02
P5: Encoders; Pin_Header_Angled_1x06
P6: BTN 1-32; Pin_Header_Angled_2x32
P14: EXTRA Pins; Pin_Header_Angled_1x05
Q1, Q2, Q3, Q4: NPN; TO-92_Inline_Narrow_Oval
R1, R3, R5, R9: 10K; Resistor_Horizontal_RM7mm
R2, R4, R6, R7, R8: 1K; Resistor_Horizontal_RM7mm
R10: 100K; Resistor_Horizontal_RM7mm
U1, U2, U3, U4: 74HC4051; DIP-16_W7.62mm_LongPads
U5: Teensy3.2; DIP-28_W15.24mm_LongPads

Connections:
+3V3: P3.2, P3.4, P3.6, R10.1, U1.16, U2.16, U3.16, U4.16, U5.26
+5V: P1.2, P1.4, P1.6, P2.1, P4.1
GND: P3.1, P3.3, P3.5, P6.2, P6.4, P6.6, P6.8, P6.10, P6.12, P6.14, P6.16, P6.18, P6.20, P6.22, P6.24, P6.26, P6.28, P6.30, P6.32, P6.34, P6.36, P6.38, P6.40, P6.42, P6.44, P6.46, P6.48, P6.50, P6.52, P6.54, P6.56, P6.58, P6.60, P6.62, P6.64, Q1.3, Q2.3, Q3.3, Q4.3, R1.2, R3.2, R5.2, R9.1, U1.6, U1.7, U1.8, U2.6, U2.7, U2.8, U3.6, U3.7, U3.8, U4.6, U4.7, U4.8, U5.1
unnamed: P1.1, Q3.1
unnamed: P1.3, Q2.1
unnamed: P1.5, Q1.1
unnamed: P4.2, R8.2
unnamed: P5.1, U5.14
unnamed: P5.2, U5.13
unnamed: P5.3, U5.12
unnamed: P5.4, U5.11
unnamed: P5.5, U5.10
unnamed: P5.6, U5.9
unnamed: P6.1, U1.1
unnamed: P6.3, U1.2
unnamed: P6.5, U1.4
unnamed: P6.7, U1.5
unnamed: P6.9, U1.15
unnamed: P6.11, U1.14
unnamed: P6.13, U1.13
unnamed: P6.15, U1.12
unnamed: P6.17, U2.1
unnamed: P6.19, U2.2
unnamed: P6.21, U2.4
unnamed: P6.23, U2.5
unnamed: P6.25, U2.15
unnamed: P6.27, U2.14
unnamed: P6.29, U2.13
unnamed: P6.31, U2.12
unnamed: P6.33, U3.1
unnamed: P6.35, U3.2
unnamed: P6.37, U3.4
unnamed: P6.39, U3.5
unnamed: P6.41, U3.15
unnamed: P6.43, U3.14
unnamed: P6.45, U3.13
unnamed: P6.47, U3.12
unnamed: P6.49, U4.5
unnamed: P6.51, U4.4
unnamed: P6.53, U4.2
unnamed: P6.55, U4.1
unnamed: P6.57, U4.12
unnamed: P6.59, U4.13
unnamed: P6.61, U4.14
unnamed: P6.63, U4.15
unnamed: P14.1, U5.16
unnamed: P14.2, U5.17
unnamed: P14.3, U5.18
unnamed: P14.4, U5.19
unnamed: P14.5, U5.20
unnamed: Q1.2, R1.1, R2.2
unnamed: Q2.2, R3.1, R4.2
unnamed: Q3.2, R5.1, R6.2
unnamed: Q4.1, R7.2, R10.2
unnamed: Q4.2, R8.1, R9.2
unnamed: R2.1, U5.5
unnamed: R4.1, U5.6
unnamed: R6.1, U5.7
unnamed: R7.1, U5.8
unnamed: U1.3, U5.25
unnamed: U1.9, U2.9, U3.9, U4.9, U5.2
unnamed: U1.10, U2.10, U3.10, U4.10, U5.3
unnamed: U1.11, U2.11, U3.11, U4.11, U5.4
unnamed: U2.3, U5.24
unnamed: U3.3, U5.23
unnamed: U4.3, U5.22

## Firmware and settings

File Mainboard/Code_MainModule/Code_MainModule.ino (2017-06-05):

/* 
 *  Modular Button Box (MOBB)
*/

#include "CONFIG.h"
#include "BUTTONS.h"
#include "AUXPins.h"
#include <Encoder.h>
#include <Bounce.h>
#include <EEPROM.h>

long positionLeft  = 0;
long positionCenter = 0;
long positionRight = 0;
unsigned long AUX1Pressed = 0;
unsigned long AUX2Pressed = 0;
unsigned long AUX3Pressed = 0;
#if EnableAux1_Button == 1
  byte AUX1PWM = EEPROM.read(AUX1_EEPROM); //read PWM value from EEPROM
#else
  byte AUX1PWM = AUX1_PWM_FIXED; //use fixed PWM value
#endif
#if EnableAux2_Button == 1
  byte AUX2PWM = EEPROM.read(AUX2_EEPROM); //read PWM value from EEPROM
#else
  byte AUX2PWM = AUX2_PWM_FIXED; //use fixed PWM value
#endif
#if EnableAux3_Button == 1
  byte AUX3PWM = EEPROM.read(AUX3_EEPROM); //read PWM value from EEPROM
#else
  byte AUX3PWM = AUX3_PWM_FIXED; //use fixed PWM value
#endif
boolean AUX1_fan_started = false;
boolean AUX2_fan_started = false;
boolean AUX3_fan_started = false;
boolean Pit_limiter_active = false;
long EEPROM_check_last = 0; //last time EEPROM values where checked for change
long EEPROM_val_change_last = 0; //last time any EEPROM stored value has changed

/* turns LED off once one of the buttons has been used */
boolean beenUsed = false;
boolean LEDon = true;



#if OutputSerial == 1
  boolean OutEEPROMSkipSend = false;
#endif
#if OutputSerial == 1 && DebugOutput == 1
  int DebugTimerStart;
  int DebugTimerStop;
#endif

/* setup encoders */
Encoder knobLeft(Encoder1PinA, Encoder1PinB);
Encoder knobCenter(Encoder2PinA, Encoder2PinB);
Encoder knobRight(Encoder3PinA, Encoder3PinB);


#if EnableMultiplexer == 0
  /* setup debounced switch object for push buttons of rotary encoders */
  Bounce EncButton1 = Bounce(Encoder1PinC, 10);
  Bounce EncButton2 = Bounce(Encoder2PinC, 10);
  Bounce EncButton3 = Bounce(Encoder3PinC, 10);
  
  /* setup push buttons on top row */
  Bounce PushPutton1 = Bounce(Button_1_Pin, 10);
  Bounce PushPutton2 = Bounce(Button_2_Pin, 10);
  Bounce PushPutton3 = Bounce(Button_3_Pin, 10);
  Bounce PushPutton4 = Bounce(Button_4_Pin, 10);
  
  /* setup debounced switch object for toggel switches */
  Bounce PushPutton5 = Bounce(Button_5_Pin, 10);
  Bounce PushPutton6 = Bounce(Button_6_Pin, 10);
  Bounce PushPutton7 = Bounce(Button_7_Pin, 10);
  Bounce PushPutton8 = Bounce(Button_8_Pin, 10);
  Bounce PushPutton9 = Bounce(Button_9_Pin, 10);
  Bounce PushPutton10 = Bounce(Button_10_Pin, 10);
  Bounce PushPutton11 = Bounce(Button_11_Pin, 10);
  Bounce PushPutton12 = Bounce(Button_12_Pin, 10);
  Bounce PushPutton13 = Bounce(Button_13_Pin, 10);
  Bounce PushPutton14 = Bounce(Button_14_Pin, 10);
#endif


Bounce PitLimiterButton = Bounce(PitLimiterPin, 10);


#ifndef AUX_ramp
void AUX_ramp(byte port);
#endif


void setup() {
  // Anything with "Serial." is only used for development ATM
  #if OutputSerial == 1
    Serial.begin(115200);
  #endif
  delay(BootUpDelay); //wait a few seconds before the "teensy keyboard" becomes active
  #if AUX_LED_Enable == 1
    pinMode(AUX_LED_Pin, OUTPUT);
    digitalWrite(AUX_LED_Pin, 0);  
  #endif
  pinMode(ledPin, OUTPUT);
  
  #if OutputSerial == 1
    while (!Serial){delay(250);}
  #endif

  /* multi plexer setup */
  #if EnableMultiplexer == 1
    pinMode(MultiplexerP9, OUTPUT);
    pinMode(MultiplexerP10, OUTPUT);
    pinMode(MultiplexerP11, OUTPUT);
    analogReadResolution(AnalogResolution);
  #endif


  #if EnableMultiplexer == 0
    /* top row push buttons */
    pinMode(Button_1_Pin, INPUT_PULLUP);
    pinMode(Button_2_Pin, INPUT_PULLUP);
    pinMode(Button_3_Pin, INPUT_PULLUP);
    pinMode(Button_4_Pin, INPUT_PULLUP);
  
    /* encoder push buttons */
    pinMode(Button_5_Pin, INPUT_PULLUP);
    pinMode(Button_6_Pin, INPUT_PULLUP);
    pinMode(Button_7_Pin, INPUT_PULLUP);
  
    /* toggle switches */
    pinMode(Button_7_Pin, INPUT_PULLUP);
    pinMode(Button_8_Pin, INPUT_PULLUP);
    pinMode(Button_9_Pin, INPUT_PULLUP);
    pinMode(Button_10_Pin, INPUT_PULLUP);
    pinMode(Button_11_Pin, INPUT_PULLUP);
    pinMode(Button_12_Pin, INPUT_PULLUP);
    pinMode(Button_13_Pin, INPUT_PULLUP);
    pinMode(Button_14_Pin, INPUT_PULLUP);
    pinMode(Button_15_Pin, INPUT_PULLUP);
    pinMode(Button_16_Pin, INPUT_PULLUP);
  #endif
  
  #if EnablePitLimiterSwitch == 1
    pinMode(PitLimiterPin, INPUT_PULLUP);
  #endif


  /* Setup AUX ports */
  pinMode(AUX1_Pin, OUTPUT);
  analogWrite(AUX1_Pin, 0 ); //start board with power turned off
  #if EnableAux1 == 1
    #if AUX1_PWM_FREQ > 0
      analogWriteFrequency(AUX1_Pin, AUX1_PWM_FREQ);
      #if OutputSerial == 1
        Serial.print("AUX1 PWM frequency set to ");
        Serial.println(AUX1_PWM_FREQ);
      #endif
    #endif
  #endif

  
  pinMode(AUX2_Pin, OUTPUT);
  analogWrite(AUX2_Pin, 0 ); //start board with power turned off
  #if EnableAux2 == 1
    #if AUX2_PWM_FREQ > 0
      analogWriteFrequency(AUX2_Pin, AUX2_PWM_FREQ);
      #if OutputSerial == 1
        Serial.print("AUX2 PWM frequency set to ");
        Serial.println(AUX2_PWM_FREQ);
      #endif
    #endif
  #endif

  
  pinMode(AUX3_Pin, OUTPUT);
  analogWrite(AUX3_Pin, 0 ); //start board with power turned off
  #if EnableAux3 == 1
    #if AUX3_PWM_FREQ > 0
      analogWriteFrequency(AUX3_Pin, AUX3_PWM_FREQ);
      #if OutputSerial == 1
        Serial.print("AUX3 PWM frequency set to ");
        Serial.println(AUX3_PWM_FREQ);
      #endif
    #endif
  #endif
  /* AUX ports done */





  #if OutputSerial == 1
    Serial.println("Modular Open Button Box (MOBB) ready...");
  #endif

  /* get any fans started */
  #if OutputSerial == 1
    Serial.print("AUX ports config");
    
    if( EnableAux1 == 0 ){
      Serial.print(" / AUX1 disabled");
    }else if( EnableAux1 == 1 && EnableAux1_Button == 1 ){
      if( AUX1_Button_Auto_Hold > 0 ){
        Serial.print(" / AUX1 ");
        Serial.print(AUX1PWM);
        Serial.print(" hold ");
        Serial.print(AUX1_Button_Auto_Hold);
        Serial.print("s");
      }else{
        Serial.print(" / AUX1 ");
        Serial.print(AUX1PWM);
      }
    }else if( EnableAux1 == 1 && EnableAux1_Button == 0 ){
      Serial.print(" / AUX1 FIX ");
      Serial.print(AUX1PWM);
    }
    
    if( EnableAux2 == 0 ){
      Serial.print(" / AUX2 disabled");
    }else if( EnableAux2 == 1 && EnableAux2_Button == 1 ){
      if( AUX2_Button_Auto_Hold > 0 ){
        Serial.print(" / AUX2 ");
        Serial.print(AUX2PWM);
        Serial.print(" hold ");
        Serial.print(AUX2_Button_Auto_Hold);
        Serial.print("s");
      }else{
        Serial.print(" / AUX2 ");
        Serial.print(AUX2PWM);
      }
    }else if( EnableAux2 == 1 && EnableAux2_Button == 0 ){
      Serial.print(" / AUX2 FIX ");
      Serial.print(AUX2PWM);
    }

    if( EnableAux3 == 0 ){
      Serial.print(" / AUX3 disabled");
    }else if( EnableAux3 == 1 && EnableAux3_Button == 1 ){
      if( AUX3_Button_Auto_Hold > 0 ){
        Serial.print(" / AUX3 ");
        Serial.print(AUX3PWM);
        Serial.print(" hold ");
        Serial.print(AUX3_Button_Auto_Hold);
        Serial.print("s");
      }else{
        Serial.print(" / AUX3 ");
        Serial.print(AUX3PWM);
      }
    }else if( EnableAux3 == 1 && EnableAux3_Button == 0 ){
      Serial.print(" / AUX3 FIX ");
      Serial.print(AUX3PWM);
    }
    Serial.println();
  #endif
  
  if( ( AUX1_fan_started == false || AUX1_fan_started == false || AUX1_fan_started == false ) &&
      ( AUX1_ENABLE_FAN_START == 1 || AUX2_ENABLE_FAN_START == 1 || AUX3_ENABLE_FAN_START == 1 ) )
  {

    #if EnableAux1 == 1
      if( EEPROM.read(AUX1_EEPROM) >= AUX1_PWM_MIN ){
        if( AUX1_fan_started == false && AUX1_ENABLE_FAN_START == 1 && AUX1_FAN_START_RAMP > AUX1PWM ){
          AUX_ramp(1);
        }
      }
   #endif

    #if EnableAux2 == 1
      if( EEPROM.read(AUX2_EEPROM) >= AUX2_PWM_MIN ){
        if( AUX2_fan_started == false && AUX2_ENABLE_FAN_START == 1 && AUX2_FAN_START_RAMP > AUX2PWM ){
          AUX_ramp(2);
        }
      }
    #endif

    #if EnableAux3 == 1
      if( EEPROM.read(AUX3_EEPROM) >= AUX3_PWM_MIN ){
        if( AUX3_fan_started == false && AUX3_ENABLE_FAN_START == 1 && AUX3_FAN_START_RAMP > AUX3PWM ){
          AUX_ramp(3);
        }
      }
    #endif
  }

} //void setup()








void send_key( int key, int del, int mod = 0, int btnhold = 0 ) {
    
  #if OutputSerial == 1 && DebugMultiplexer == 0
    Serial.print("send_key() / ");
    Serial.print("Mod:");
    Serial.print(mod);
    Serial.print(" / key:");
    Serial.print(key);
    Serial.print(" / kb:");
    key_int2str(key, mod);
    Serial.println();
  #endif

  #if OutputKeyboard == 1 && DebugMultiplexer == 0
    Keyboard.set_modifier(mod);
    Keyboard.set_key1(key);
    Keyboard.send_now();

    if ( btnhold == 0 ) {
      delay(del); //iRacing will not detect the key without a short delay
      release_key();
    }
  #endif


  beenUsed = true;

} //void send_key()




/*
 ##############
 # LOOOOOOOOP #
 ##############
*/
void loop() {


  #if OutputSerial == 1 && DebugOutput == 1
    DebugTimerStart = millis();
  #endif
  
  /* the LED is distracting when it's dark in the room. this turns it off after the first button use */
  if ( beenUsed == true && LEDon == true ) {
    digitalWrite(ledPin, LOW);
    LEDon = false;
  } else if ( beenUsed == false ) {
    digitalWrite(ledPin, HIGH);
  }
  
  
  /**
  * pit limiter is permanent ON/OFF switch so this is must be handeled seperately
   */
  #if EnablePitLimiterSwitch == 1    
    pit_limit();
  #endif

  /* button check start */
  check_rotary_encoders();

  #if EnableMultiplexer == 1
    check_multiplexed_buttons();
  #else
    check_buttons();
    check_encoder_switches();
  #endif
  /* button check done */


  #if OutputSerial == 1 && DebugOutput == 1
    DebugTimerStop = millis();
  
    Serial.print("Start: ");
    Serial.print(DebugTimerStart);
    Serial.print(" Stop: ");
    Serial.println(DebugTimerStop);
  #endif

  eeprom_update_pwm();

  #if AUX1_Button_Auto_Hold > 0 || AUX2_Button_Auto_Hold > 0 || AUX3_Button_Auto_Hold > 0
    release_aux_button();
  #endif


  AUX_ramp(0); //maintain AUX ramps
}



 /*
 * handles pit limiter operation
 * pit limiter is permanent ON/OFF switch so this is must be handeled seperately
 */
 #if EnablePitLimiterSwitch == 1
 void pit_limit(){
    if (PitLimiterButton.update()) {

      #if PitLimiterIgnoreOnAux == 1
        if( AUX1Pressed != 0 || AUX2Pressed != 0 || AUX3Pressed != 0 ){
            #if OutputSerial == 1
              Serial.println("Pit limiter ignored - AUX ist active");
            #endif
            return;
        }
      #endif
  
      if (PitLimiterButton.fallingEdge()) {
        Pit_limiter_active = true;
        #if OutputSerial == 1
          Serial.println("Pit limiter ON");
        #endif
        send_key(PitLimiterKey, BUTTON_HOLD, PitLimiterMod, PitLimiterHold );
  
        
      }else{
        if( Pit_limiter_active == true ){
          Pit_limiter_active = false;
          #if OutputSerial == 1
            Serial.println("Pit limiter OFF");
          #endif
          send_key(PitLimiterKey, BUTTON_HOLD, PitLimiterMod, PitLimiterHold );
        }
      }
    }  
 }
 #endif


/*
 * was supposed to only ramp AUX ports but now maintains values as well. needs to be rewritten for cleanup later ... lets test it first
 * ramps a ports .... was added later needs to be improved to use defined values from config files
 * port == 0 check current ramps or 1,2,3 for AUX
 */
void AUX_ramp( byte port ){
  static unsigned long ramp_start[3] = { 0, 0, 0 }; // 0 = not active, >0 = ramping
  byte ramp_value[3] = { AUX1_FAN_START_RAMP, AUX2_FAN_START_RAMP, AUX3_FAN_START_RAMP};
  byte ramp_pin[3] = { AUX1_Pin, AUX2_Pin, AUX3_Pin};
  byte ramp_enabled[3] {AUX1_ENABLE_FAN_START, AUX2_ENABLE_FAN_START, AUX3_ENABLE_FAN_START };
  byte pwm_vals[3] = { AUX1PWM, AUX2PWM, AUX3PWM};
  byte aux_active[3] = { EnableAux1, EnableAux2, EnableAux3};

  if( port == 0 ) {
    // maintain ramps
    for( byte x=0 ; x < 3 ; ++x ){
      if( ramp_start[x] > 0 && (ramp_start[x] + AUX_RAMP_TIME) < millis() ){
        analogWrite(ramp_pin[x], pwm_vals[x] );
        ramp_start[x]  = 0;
        #if OutputSerial == 1
          Serial.print("Ramp OFF AUX ");
          Serial.print(x+1);
          Serial.print(" pin ");
          Serial.print(ramp_pin[x]);
          Serial.print(" speed ");
          Serial.print(pwm_vals[x]);
          Serial.println();
        #endif
      }else if( ramp_start[x] == 0 ){
        if( aux_active[x] == 1 ) {  analogWrite(ramp_pin[x], pwm_vals[x]);}
        else{ analogWrite(ramp_pin[x], 0);}
      }
    }
    return;
  }


  byte address = port - 1; //array address or port
  if( ramp_start[address] == 0 ){
    if( ramp_enabled[address] == 1 ){
      analogWrite(ramp_pin[address], ramp_value[address] );
      ramp_start[address] = millis();
  
      #if OutputSerial == 1
        Serial.print("Ramp ON AUX ");
        Serial.print(port);
        Serial.print(" pin ");
        Serial.print(ramp_pin[address]);
        Serial.print(" speed ");
        Serial.print(ramp_value[address]);
        Serial.println();
      #endif
    }
    return;
  }
}



#if AUX1_Button_Auto_Hold > 0 || AUX2_Button_Auto_Hold > 0 || AUX3_Button_Auto_Hold > 0
/**
 * checks if any AUX buttons need to be released
 */
void release_aux_button(){
  unsigned long timenow = millis();

  if( AUX1_Button_Auto_Hold > 0 && AUX1Pressed > 0 && timenow > ( AUX1Pressed + AUX1_Button_Auto_Hold * 1000) ){
    #if OutputSerial == 1
      Serial.print("AUX1 auto hold released / PWM ");
      Serial.print(AUX1PWM);
      Serial.print(" / AuxMod ");
      Serial.print(AUX1_Button_Mod);
      Serial.println(" / release_aux_button()");
    #endif
    AUX1Pressed = 0;
    #if AUX_LED_Enable == 1
      analogWrite(AUX_LED_Pin, 0);
    #endif
  }

  if( AUX2_Button_Auto_Hold > 0 && AUX2Pressed > 0 && timenow > ( AUX2Pressed + AUX2_Button_Auto_Hold * 1000) ){
    #if OutputSerial == 1
      Serial.print("AUX2 auto hold released / PWM ");
      Serial.print(AUX2PWM);
      Serial.print(" / AuxMod ");
      Serial.print(AUX2_Button_Mod);
      Serial.println(" / release_aux_button()");
    #endif
    AUX2Pressed = 0;
    #if AUX_LED_Enable == 1
      analogWrite(AUX_LED_Pin, 0);
    #endif
  }

  if( AUX3_Button_Auto_Hold > 0 && AUX3Pressed > 0 && timenow > ( AUX3Pressed + AUX3_Button_Auto_Hold * 1000) ){
    #if OutputSerial == 1
      Serial.print("AUX3 auto hold released / PWM ");
      Serial.print(AUX3PWM);
      Serial.print(" / AuxMod ");
      Serial.print(AUX3_Button_Mod);
      Serial.println(" / release_aux_button()");
    #endif
    AUX3Pressed = 0;
    #if AUX_LED_Enable == 1
      analogWrite(AUX_LED_Pin, 0);
    #endif
  }
  
}
#endif





/** compares current pwm vs the eeprom value every few seconds
 *  updates it if the differ
 */
void eeprom_update_pwm(){
  int must_pass = millis() - (EEPROM_storage_loop * 1000);

  #if OutputSerial == 1 && DebugOutput == 1
    Serial.print("must_pass:  ");
    Serial.print(must_pass);
    Serial.print(" now:  ");
    Serial.print(EEPROM_check_last);
    Serial.println(" / eeprom_update_pwm()");
  #endif
  

  if( EEPROM_check_last == 0 ) {
    //system just booted, wait at least for "EEPROM_storage_loop" delay
    EEPROM_check_last = millis();
    EEPROM_val_change_last = millis();
    
  }else if( EEPROM_check_last < must_pass && EEPROM_val_change_last < must_pass ){
    #if OutputSerial == 1
      OutEEPROMSkipSend = false;
      Serial.println("comparing EEPROM values / eeprom_update_pwm()");
    #endif

    if( EnableAux1_Button == 1 && EEPROM.read(AUX1_EEPROM) != AUX1PWM ){
      #if OutputSerial == 1
        Serial.print("INFO: AUX1 EEPROM address ");
        Serial.print(AUX1_EEPROM);
        Serial.print(" write value ");
        Serial.print(AUX1PWM);
        Serial.println(" / eeprom_update_pwm()");
      #endif
      
      #if EEPROMWrite == 1
        EEPROM.write(AUX1_EEPROM, AUX1PWM);
      #else
        #if OutputSerial == 1
          Serial.println("INFO: write disabled by configuration / eeprom_update_pwm()");
        #endif        
      #endif      
    }

    if( EnableAux2_Button == 1 && EEPROM.read(AUX2_EEPROM) != AUX2PWM ){
      #if OutputSerial == 1
        Serial.print("INFO: AUX2 EEPROM address ");
        Serial.print(AUX2_EEPROM);
        Serial.print(" write value ");
        Serial.print(AUX2PWM);
        Serial.println(" / eeprom_update_pwm()");
      #endif
      
      #if EEPROMWrite == 1
        EEPROM.write(AUX2_EEPROM, AUX2PWM);
      #else
        #if OutputSerial == 1
          Serial.println("INFO: write disabled by configuration / eeprom_update_pwm()");
        #endif
      #endif      
    }

    if( EnableAux3_Button == 1 && EEPROM.read(AUX3_EEPROM) != AUX3PWM ){
      #if OutputSerial == 1
        Serial.print("INFO: AUX3 EEPROM address ");
        Serial.print(AUX3_EEPROM);
        Serial.print(" write value ");
        Serial.print(AUX3PWM);
        Serial.println(" / eeprom_update_pwm()");
      #endif
      
      #if EEPROMWrite == 1
        EEPROM.write(AUX3_EEPROM, AUX3PWM);
      #else
        #if OutputSerial == 1
          Serial.println("INFO: write disabled by configuration / eeprom_update_pwm()");
        #endif
      #endif
    }

    
    EEPROM_check_last = millis(); //update "last check counter"
  }else{
    #if OutputSerial == 1
      if(  OutEEPROMSkipSend == false && EEPROM_check_last < must_pass && EEPROM_val_change_last > must_pass) {
        OutEEPROMSkipSend = true;
        Serial.println("skipping EEPROM checks - value recently changed / eeprom_update_pwm()");
      }
    #endif
  }




}



void release_key() {
  #if OutputSerial == 1 && DebugMultiplexer == 0
    Serial.println("ran release_key()");
  #endif

  #if OutputKeyboard == 1 && DebugMultiplexer == 0
    Keyboard.set_modifier(0);
    Keyboard.set_key1(0);
    Keyboard.send_now();
  #endif
}


#if OutputSerial == 1
// returns keyboard string value for constant - NULL on failure
void key_int2str( int value, int mod ) {
  #define asize 28
  int Code[asize] = { 16395, 16393, 16392, 16391, 16397, 16405, 16402, 16396, 16390, 16389, 16394, 16399, 16388, 16401, 16413, 16411, 16414, 16398, 16418, 16406, 16407, 16408, 16409, 16410, 16412, 16404, 16403, 16400 };
  char Key[asize] = { 'h', 'f', 'e', 'd', 'j', 'r', 'o', 'i', 'c', 'b', 'g', 'l', 'a', 'n', 'y', 'x', '1', 'k', '5', 's', 't', 'u', 'v', 'w', 'z', 'q', 'p', 'm'  };

  //hardcode some values
  if( value == 16425 ){
    Serial.print("<ESC>");
    return;
  }else if( value == 16428 ){
    Serial.print("<SPACE>");
    return;
  }else if( value == 61520 ){
    Serial.print("<LEFT-ARROW>");
    return;
  }else if( value == 61519 ){
    Serial.print("<RIGHT-ARROW>");
    return;
  }else if( value == 61522 ){
    Serial.print("<UP-ARROW>");
    return;
  }else if( value == 61521 ){
    Serial.print("<DOWN-ARROW>");
    return;
  }

  for( int i=0 ; i < asize ; i++ ){
    
    if( Code[i] == value ){
      if( mod == 0 ) {
         Serial.print( Key[i] );
      }else{
        String upper = Key[i];
        Serial.print( upper.toUpperCase() );
      }
      return;
    }
  }
}
#endif

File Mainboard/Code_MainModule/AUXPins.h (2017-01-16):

//Pin for feedback LED. High when AUX key is pushed or hold is active
#define AUX_LED_Enable 1 // 1 to enable LED feedback, default: 0
#define AUX_LED_Pin 13 // pin number of LED
#define AUX_LED_PWD 255 //PWM value for output




#define EnableAux1 1 // Enable / Disable AUX port. Set this to 1 to use the feature
#define EnableAux1_Button 1 //hold down a button to control the PMW output
#define AUX1_Pin 6 // 5Volt -  fan or UV LED pin
#define AUX1_Button KEY_A // hold this button and use encoder left/right to adjust PWM output on port
#define AUX1_Button_Mod 0 //set to 'MODIFIERKEY_SHIFT' to a capital letter
#define AUX1_Button_Auto_Hold 6 //seconds the button is "held" in software to allow one hand operation. 0 = hold and turn knob 0< push, release button and turn knop within the time your set here
#define AUX1_PWM_FIXED 100 //fixed PWM value used when "EnableAux*_Button" is not set to 1
#define AUX1_PWM_CHANGE 5 //increase or decrease PWM by this much
#define AUX1_PWM_MAX 255 //max valueo for pwm AoBLSOLUTE MAX 255 !!!!
#define AUX1_PWM_MIN 4 //min value for pwm ABSOLUTE MIN 0 !!!!
#define AUX1_PWM_FREQ 100   //PWM frequency in Hz - set to zero to use default value of 488.28Hz
                            //Pins 3 & 4 share FTM1, Pins 5,6,9,10,20,21,22,23 share FTM0 and Pins 25,26 share FTM2
                            //setting a frequency on one pin will set the same frequency on all other pins connected to the same timer!
                            // https://www.pjrc.com/teensy/td_pulse.html
#define AUX1_ENABLE_FAN_START 1 //0 to disable or 1 to ramp up this port when turned on
#define AUX1_FAN_START_RAMP 100 // PWM value used to get the fan spinning
#define AUX1_EEPROM 0 // EEPROM address






#define EnableAux2 1 // Enable / Disable AUX port. Set this to 1 to use the feature
#define EnableAux2_Button 1 //hold down a button to control the PMW output
#define AUX2_Pin 5 // 5Volt - fan or UV LED pin
#define AUX2_Button KEY_B // hold this button and use encoder left/right to adjust PWM output on port
#define AUX2_Button_Mod 0 //set to 'MODIFIERKEY_SHIFT' to a capital letter
#define AUX2_Button_Auto_Hold 0 //seconds the button is "held" in software to allow one hand operation. 0 = hold and turn knob 0< push, release button and turn knop within the time your set here
#define AUX2_PWM_FIXED 100 //fixed PWM value used when "EnableAux*_Button" is not set to 1
#define AUX2_PWM_CHANGE 10 //increase or decrease PWM by this much
#define AUX2_PWM_MAX 255 //max value for pwm ABLSOLUTE MAX 255 !!!!
#define AUX2_PWM_MIN 9 //min value for pwm ABSOLUTE MIN 0 !!!!
#define AUX2_PWM_FREQ 100   //PWM frequency in Hz - set to zero to use default value of 488.28Hz
                            //Pins 3 & 4 share FTM1, Pins 5,6,9,10,20,21,22,23 share FTM0 and Pins 25,26 share FTM2
                            //setting a frequency on one pin will set the same frequency on all other pins connected to the same timer!
                            // https://www.pjrc.com/teensy/td_pulse.html
#define AUX2_ENABLE_FAN_START 0 //0 to disable or 1 to ramp up this port when turned on
#define AUX2_FAN_START_RAMP 100 // PWM value used to get the fan spinning
#define AUX2_EEPROM 1 // EEPROM address





#define EnableAux3 1 // Enable / Disable AUX port. Set this to 1 to use the feature
#define EnableAux3_Button 1 //hold down a button to control the PMW output
#define AUX3_Pin 4 // 5Volt - fan or UV LED pin
#define AUX3_Button KEY_C // hold this button and use encoder left/right to adjust PWM output on port
#define AUX3_Button_Mod 0 //set to 'MODIFIERKEY_SHIFT' to a capital letter
#define AUX3_Button_Auto_Hold 0 //seconds the button is "held" in software to allow one hand operation. 0 = hold and turn knob 0< push, release button and turn knop within the time your set here
#define AUX3_PWM_FIXED 100 //fixed PWM value used when "EnableAux*_Button" is not set to 1
#define AUX3_PWM_CHANGE 10 //increase or decrease PWM by this much
#define AUX3_PWM_MAX 255 //max value for pwm ABLSOLUTE MAX 255 !!!!
#define AUX3_PWM_MIN 9  //min value for pwm ABSOLUTE MIN 0 !!!!
#define AUX3_PWM_FREQ 0   //PWM frequency in Hz - set to zero to use default value of 488.28Hz
                          //Pins 3 & 4 share FTM1, Pins 5,6,9,10,20,21,22,23 share FTM0 and Pins 25,26 share FTM2
                          //setting a frequency on one pin will set the same frequency on all other pins connected to the same timer!
                          // https://www.pjrc.com/teensy/td_pulse.html
#define AUX3_ENABLE_FAN_START 0 //0 to disable or 1 to ramp up this port when turned on
#define AUX3_FAN_START_RAMP 100 // PWM value used to get the fan spinning
#define AUX3_EEPROM 2 // EEPROM address

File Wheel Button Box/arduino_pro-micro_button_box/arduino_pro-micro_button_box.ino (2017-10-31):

/*
 * Stand Alone Wheel Button Box for the Arduino Pro Micro
 * The buttons for the wheel button box may be connected to the MOBB-PCB or to an
 * Arduino Pro Micro using this code
 * 
 * 
*/

/* developemnt stuff - remove when done */
#define debug_delay  2000
unsigned long debug_last = 0;
#define testing_oled false
/* developemnt stuff - remove when done */


#include "CONFIG.h"
#include "Bounce2.h" 
#include <EEPROM.h>
#include <Keyboard.h>

#if testing_oled == true
  #include <SPI.h>
  #include <Wire.h>
  #include <Adafruit_GFX.h>
  #include <Adafruit_SSD1306.h>
  
  #define LOGO16_GLCD_HEIGHT 16 
  #define LOGO16_GLCD_WIDTH  16 
  #define OLED_RESET 4
  Adafruit_SSD1306 display(OLED_RESET);
#endif


/*keep times of button presses */
unsigned long ButtonPressed[13]; //stores the time when the key press has been detected
unsigned long ButtonSend[13];    //stores last time the key has been sent to the computer
unsigned long JoystickMoved[2];  //stores the time when a joystick move has been detected
unsigned long JoystickSend[2];   //stores last time the key has been sent to the computer

/* setup debounce library for all push buttons*/
Bounce Buttons[14] = {
  Bounce(Button_1_Pin, BUTTON_DEBOUNCE),
  Bounce(Button_2_Pin, BUTTON_DEBOUNCE),
  Bounce(Button_3_Pin, BUTTON_DEBOUNCE),
  Bounce(Button_4_Pin, BUTTON_DEBOUNCE),
  Bounce(Button_5_Pin, BUTTON_DEBOUNCE),
  Bounce(Button_6_Pin, BUTTON_DEBOUNCE),
  Bounce(Button_7_Pin, BUTTON_DEBOUNCE),
  Bounce(Button_8_Pin, BUTTON_DEBOUNCE),
  Bounce(Button_9_Pin, BUTTON_DEBOUNCE),
  Bounce(Button_10_Pin, BUTTON_DEBOUNCE),
  Bounce(Button_11_Pin, BUTTON_DEBOUNCE),
  Bounce(Button_12_Pin, BUTTON_DEBOUNCE),
  Bounce(Shifter_1_Pin, BUTTON_DEBOUNCE),
  Bounce(Shifter_2_Pin, BUTTON_DEBOUNCE)
};

/* setup array to make processing buttons simpler */
byte ButtonPins[14] = { Button_1_Pin, Button_2_Pin, Button_3_Pin, Button_4_Pin,
                        Button_5_Pin, Button_6_Pin, Button_7_Pin, Button_8_Pin,
                        Button_9_Pin, Button_10_Pin, Button_11_Pin, Button_12_Pin, 
                        Shifter_1_Pin, Shifter_2_Pin };
char ButtonKeys[14][1] = { Button_1_Key, Button_2_Key, Button_3_Key, Button_4_Key,
                        Button_5_Key, Button_6_Key, Button_7_Key, Button_8_Key,
                        Button_9_Key, Button_10_Key, Button_11_Key, Button_12_Key, 
                        Shifter_1_Key, Shifter_2_Key };
char ButtonMods[14][1] = { Button_1_Mod, Button_2_Mod, Button_3_Mod, Button_4_Mod,
                        Button_5_Mod, Button_6_Mod, Button_7_Mod, Button_8_Mod,
                        Button_9_Mod, Button_10_Mod, Button_11_Mod, Button_12_Mod, 
                        Shifter_1_Mod, Shifter_2_Mod };

/* setup array for joystick to make it simpler to read it */
byte JoystickPins[2] = { Joystick_1_Pin, Joystick_2_Pin };
char JoystickKeys[2][2][1] = { { Joystick_1_KeyA, Joystick_1_KeyB }, { Joystick_2_KeyA, Joystick_2_KeyB } };
char JoystickMods[2][2][1] = { { Joystick_1_ModA, Joystick_1_ModB }, { Joystick_2_ModA, Joystick_2_ModB } };

int  JoyStickCenters[2] = { Joystick_1_Center, Joystick_2_Center };
int  JoyStickMoveMin[2] = { Joystick_1_Move_Min, Joystick_2_Move_Min };
byte  JoyStickDirection[2] = { 0, 0 }; // 0 center, 1=direction 1 2=direction 2
byte JoyStickMoved = 0; // lockup other axis when joystick is moved. Only allows move left/right or up/down but not at the same time. 0 = no move, 1= joystick direction 1, 2= joy direction 2

/* serial receive stuff */
boolean serial_done = false;
String serial_cmd;  // holds the received command
boolean button_enabled = false; //don't send commands until the nano is connected to the PC


void setup() {
  
  
  for( byte x=0 ; x < sizeof(ButtonPins)/sizeof(byte) ; ++x ){
    pinMode( ButtonPins[x], INPUT_PULLUP);
    ButtonPressed[x] = 0;
    ButtonSend[x] = 0;
  }
  for( byte x=0 ; x < sizeof(JoystickPins)/sizeof(byte) ; ++x ){
    pinMode( JoystickPins[x], INPUT);
    JoystickMoved[x] = 0;
    JoystickSend[x] = 0;
  }

  #if testing_oled == true
    display.begin(SSD1306_SWITCHCAPVCC, 0x3C);  // initialize with the I2C addr 0x3C (for the 128x32)
  #endif

  #if DebugSerialOut == true
  Serial.begin(115200);
  while (!Serial) {
    ; // wait for serial port to connect. Needed for native USB port only
    delay(50);
  }
  Serial.println("ready");
  delay(4000);
  #endif

  #if KeyboardEnabled == true
    Keyboard.begin();
  #endif
}


void loop() {
  /* listen for commands from PC */
  if (serial_done == true)
  {
    //maybe add config options later so the unit may be configured without compiling the code again
    serial_done = false;
    serial_cmd = "";
  }


 check_buttons();
 check_joystick();

}


/* does the actual key pessing */
void sendKey( char Key, char Mod){

  #if KeyboardEnabled == true
    Keyboard.press(Mod);
    Keyboard.press(Key);
  #endif
  
  #if DebugSendKey == true
    Serial.print("sendKey key:");
    Serial.print(Key);
    Serial.print(" mod:");
    Serial.println(Mod);
  #endif
}

/* release the pressed key */
void releaseKey( char Key, char Mod){

  #if KeyboardEnabled == true
    Keyboard.release(Mod);
    Keyboard.release(Key);
  #endif

  #if DebugSendKey == true
    Serial.print("releaseKey key:");
    Serial.print(Key);
    Serial.print(" mod:");
    Serial.println(Mod);
  #endif
}
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

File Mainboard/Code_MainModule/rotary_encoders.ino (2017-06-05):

/* code for rotary encoders goes here */


#if EnableMultiplexer == 0
/* check push buttons of encoders */
void check_encoder_switches(){

  check_button( EncButton1, Encoder1KeyC, Encoder1ModC, Encoder1HoldC );
  
  check_button( EncButton2, Encoder2KeyC, Encoder2ModC, Encoder2HoldC );
  
  check_button( EncButton3, Encoder3KeyC, Encoder3ModC, Encoder3HoldC );
}
#endif


/* check rotary encourders */
void check_rotary_encoders(){
  long newLeft, newCenter, newRight;
  int AUX1PWM_new = 0;
  int AUX2PWM_new = 0;
  int AUX3PWM_new = 0;
  
  newLeft = knobLeft.read()/4;
  newCenter = knobCenter.read()/4;
  newRight = knobRight.read()/4;
  if (newLeft != positionLeft || newCenter != positionCenter || newRight != positionRight ){

      if( newLeft > positionLeft ){
        #if OutputSerial == 1
          Serial.println("EncLeft:left / check_rotary_encoders()");
        #endif
        send_key(Encoder1KeyA, BUTTON_HOLD, Encoder1ModA );
        
      }else if( newLeft < positionLeft ){
        #if OutputSerial == 1
          Serial.println("EncLeft:right / check_rotary_encoders()");
        #endif
        send_key(Encoder1KeyB, BUTTON_HOLD, Encoder1ModB );
      }

      if( newCenter > positionCenter ){
        #if OutputSerial == 1
          Serial.println("EncCenter:left / check_rotary_encoders()");
        #endif
        send_key(Encoder2KeyA, BUTTON_HOLD, Encoder2ModA );
        
      }else if( newCenter < positionCenter ){
        #if OutputSerial == 1
          Serial.println("EncCenter:right / check_rotary_encoders()");
        #endif
        send_key(Encoder2KeyB, BUTTON_HOLD, Encoder2ModB );
      }
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

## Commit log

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2016-05-28 * STL files for v2 body and face plate * added v3 with additional center post on top and bottom row
    [Face Plate Box MAIN - v3 - Top Row Ignition + 3 buttons.STL, Face Plate Box MAIN - v3 - Top Row 4 Buttons.STL, Face Plate Box MAIN -v3.SLDPRT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]
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2016-06-04 * complete holder assembly for 10mm LED holder. untestet, LED holes are currently 11 mm. needs two M3x20mm screws and nuts
    [UV Lamp Mount - 10mm LED - no reflector design.SLDASM, UV Lamp Mount - arm - 10mm LED - no reflector design.SLDPRT, UV Lamp Mount - arm - 10mm LED - no reflect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]
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2016-06-04 * updated angles since they where to shallow. tested previous design with 5mm UV LED. 10mm parts should be here in a few days
    [UV Lamp Mount - 10mm LED - no reflector design.SLDASM, UV Lamp Mount - base - 10mm LED - no reflector design.SLDPRT, UV Lamp Mount - base - 10mm LED - no refle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]
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2016-06-04 * added assembly of v4 and screenshot of rendering. will print this in black PLA for prototype 3
    [Main Modul - Fully Assembled - v4.SLDASM]
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2016-06-05 * new idea for side box .... why add more rotary encoders when the existing three work fine. instead add more buttons which may open the black box menu, then use existing encoders to edjust values * 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
    [Main Modul - Fully Assembled - v4.SLDASM, Main Module - Face Plate - v4.SLDPRT, Side Box Left assembled with Main Body - v2 Face Plate.SLDASM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]
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2016-06-12 * new face plates * increased hole size for push button from 12.2mm to 13mm to compensate for lip
    [Encoder Knob 1.3-HEX.STL, Encoder Knob 1.3.SLDPRT, Main Module - Face Plate - v4 - TOP ROW 1x16mm + 3x12mm.STL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]
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2016-09-26 * WIP for v5 case, new idea is not mount two main boxes next to or below another
    [Main Module - Body - v5.SLDPRT]
2016-09-26 * Body v5 is taler to give more room for main board blow * tweaked code to match dev setup * AUX support - fan and UV LED support next
    [Main Module - Body - v5.SLDPRT]
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2016-10-01 * first face plates for version 5 ... same size as version 4
    [Main Module - Face Plate - v5 - TOP ROW 1x16mm + 3x13mm.STL, Main Module - Face Plate - v5 - TOP ROW 4x13mm - BOTTOM encoders left.STL, Main Module - Face Plat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]
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2016-10-02 * kicad schematic for multi plexed main board. this is a WIP
    [OSBB-v1.kicad_pcb, OSBB-v1.sch]
2016-10-15 * fixed wrong pin for PitLimiterPin * changed default key for encoder buttons so every button has a unique output
    [CONFIG.h]
2016-10-15 * reduced PWM frequency to allow voltage regulation through an optical isolator tested with a 12V "noctua" fan * AUX ports where not initialized when multiplexing was disabled * found an issue when A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
    [Code_MainModule.ino]
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2016-10-16 * enabled AUX3 again ... there was not bug
    [Code_MainModule.ino, multiplexer_4051.ino]
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2016-10-17 * tweaked config options * now possible to set AUX ports to a fixed value and not enable a button to control PWM output of the port * added a few more compiler conditions to omit some AUX check when 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
    [CONFIG.h, Code_MainModule.ino, multiplexer_4051.ino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]
2016-10-17 * encoder left/right was reversed when adjusting AUX PWM
    [rotary_encoders.ino]
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2016-10-26 * Added pin numbers to Teensy library part to match DIL-28 housing
    [OSBB-v1.sch]
2016-10-27 * changed pinout of headers for buttons. now consisten GND on 1,3,5,7
    [OSBB-v1.sch]
2016-10-28 * updated schematic to use 2x32 pin header to make it easier to connect PCB * PCB is connected, still needs to be checked
    [OSBB-v1.kicad_pcb, OSBB-v1.sch]
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2016-10-31 * GND traces thicker from 0.25mm to 0.5mm * +5V traces thicker from 0.25mm to 0.75mm
    [OSBB-v1.kicad_pcb]
2016-10-31 * tweaked layout of a few traces * added two M2 mounting holes
    [OSBB-v1.kicad_pcb]
2016-10-31 * PCB redesign as RC2. better part placement for shorter traces * adjusted the order of some pins connecting to the header to make routing those traces easier * thicker supply and ground traces
    [OSBB-v1-RC1.kicad_pcb, OSBB-v1-RC2.kicad_pcb, OSBB-v1.sch]
2016-11-01 * added circuit for pit limiter switch onto the PCB * added open HW logo
    [OSBB-v1-RC3.kicad_pcb, OSBB-v1.sch]
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2016-11-02 * two tracks to close. had this corrected on Gerber files to manfacturer but did not push it. this is the fix.
    [OSBB-v1-RC4-B.Cu.GBL, OSBB-v1-RC4-B.Mask.GBS, OSBB-v1-RC4-B.SilkS.GBO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]
2016-11-02 * increased spacing around a few more traces. passes for 0,23mm spacing now
    [OSBB-v1.kicad_pcb]
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2016-11-03 * added solder pads for another fan header to the PCB. there is room ... might as well
    [fan controller v1.kicad_pcb, fan controller v1.sch]
2016-11-06 * corrected molex connectors on Fan PCB * added optional LED to show "ON" state
    [fan controller v1.kicad_pcb, fan controller v1.sch]
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2016-11-20 * should be correct now
    [CONFIG.h]
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2016-11-20 * PCB RC5-DEV adjusting button schematic to pull input low * now with M3 mounting hols * fixed missing silkscreen
    [OSBB-v1.kicad_pcb, OSBB-v1.sch]
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2016-11-21 * RC5-dev joined missing ground traces for right side of board
    [OSBB-v1.kicad_pcb]
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2016-11-21 * changed orientation of cap to give more room around screw * adjusted distance between lower pins (aux, 3v...) * more labels
    [OSBB-v1.kicad_pcb]
2016-11-21 * fixed missing tracks from last release
    [OSBB-v1.kicad_pcb]
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2016-11-21 * added a few labels since I don't export all vlues for the gerber files * gerber files for RC5
    [OSBB-v1-B.Cu.gbl, OSBB-v1-B.Mask.gbs, OSBB-v1-B.SilkS.gbo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]
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2016-11-22 * RC1 final for fan controller * ordered V-CUT version today since that fits into 5*5cm order size
    [fan controller v1-VCUT.kicad_pcb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]
2016-11-23 * aux breakout PCB. this board will be mounted to the case and provide access to AUX connectors through a hole in the case. mounting hole dimensions on back of PCB
    [aux-breakout.kicad_pcb, aux-breakout.sch]
2016-11-23 * WIP - body for RC5 PCB and AUX break out board
    [Main Module - Body - v6-RC5_PCB.SLDPRT]
2016-11-28 * gerber files where missing F+B solder mask layers
    [fan controller v1-B.Cu.gbr, fan controller v1-B.Mask.gbr, fan controller v1-B.SilkS.gbr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]
2016-12-08 * code adjusted for PCB RC5 circuit design. should not work with non-multiplexed at the moment
    [CONFIG.h, multiplexer_4051.ino]
2016-12-08 * PCB RC5 has arrived. Looks like the floating pin bug has been fixed. Multiplexed buttons are now pulled LOW through a 10K resistor when idle and HIGH when a button is pushed. final test when I scre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
2016-12-11 * current work of PCB RC6 - WIP * added PTC fuses for 3.3V and 5V to protect the PC in case of accidental short circuit * added 2x1 straight pin header which connects to pin13. this may late be used 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
    [OSBB-v1.kicad_pcb, OSBB-v1.sch]
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2016-12-15 * fixed values in schematic
    [fan controller v1.sch]
2016-12-15 * increased hole diameter and pad size for molex connector and screw terminals
    [fan controller v1.kicad_pcb]
2016-12-15 * fan boards arrived, some holes are too tight. Corrected in RC2 PCB revision
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2017-01-15 * updated schematic for version 1.0 from RC6 * adjusted silkscreen positions * replaced RR6 and RR5 footprint, removed pin 1 indicator * C4 now through hole * removed vias from 32pin supply line
    [OSBB-v1.kicad_pcb, OSBB-v1.sch]
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2017-01-15 * RC2 breakout board with correct hole size for 3 pin molex connector
    [aux-breakout-RC1.kicad_pcb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]
2017-01-15 * RC2 fan board with correct hole size for 3 pin molex connector
    [fan controller v1-B.Cu.gbr, fan controller v1-B.Mask.gbr, fan controller v1-B.SilkS.gbr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]
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2017-01-22 * moved all components to top side to allow for cheaper manufcaturing * rearanged multiplexers to make room for bottom resistors
    [MOBB-v1.0-SMD.kicad_pcb]
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2017-02-26 * final tweaks to MainBoard SMD RC1 release. this is for testing only at this point
    [MOBB-v1.0-SMD-B.Cu.gbl, MOBB-v1.0-SMD-B.Mask.gbs, MOBB-v1.0-SMD-B.SilkS.gbo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]
2017-03-07 * added option to turn the pit limiter back off when it gets stuck after a car reset. activate AUX and turn pit limiter off. this will not send a key press (on by default, disable using "PitLimiterIg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
    [BUTTONS.h, Code_MainModule.ino]
2017-03-10 * known issues update for fan board and PCB v1.0
2017-03-10 * fan controller board RC3 - this should fix the LED jumper issue from RC2 * increased size of some solder pads * all GND now with thermal relieve * moved LED down by 0,5mm to make "CUT" area larger 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
    [fan controller v1-B.Cu.gbr, fan controller v1-B.Mask.gbr, fan controller v1-B.SilkS.gbr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]
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2017-06-05 * added AUX ramp support when ever PWM goes from 0 (OFF) to +1 still needs to be enabled using AUXn_ENABLE_FAN_START in AUXPins.h * fixed how "AUXn_PWM_MIN" was handled when going from OFF to ON * "b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
    [Code_MainModule.ino, multiplexer_4051.ino, rotary_encoders.ino]
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2017-06-22 * added 3D model for a G27 to Momo / Sparko / OMP wheel adapter
    [G27 to Sparko - Momo Adapter.SLDPRT]
2017-06-23 * thicker to allow for the G27 screw heads to sink into the plate * momo / sparko screws should go in from behind
    [G27 to Sparko - Momo Adapter.SLDPRT]
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2017-08-11 * corrected analog pin usage
    [CONFIG.h, arduino_nano_button_box.ino]
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2017-10-31 * added "other axis lockout" so joystick only moves on direction at a time (x or y) instead of diagonal (x and y) * fixed invalid setting "JoysticksGetValues" should be "DebugJoysticksGetValues"
    [arduino_pro-micro_button_box.ino]

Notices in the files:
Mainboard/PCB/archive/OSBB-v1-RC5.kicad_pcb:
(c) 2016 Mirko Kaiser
